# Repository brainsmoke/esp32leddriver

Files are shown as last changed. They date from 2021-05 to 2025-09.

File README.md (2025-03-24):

# LED Driver for 3D sculptures based on an ESP32 with PSRAM + an STM32F0XX

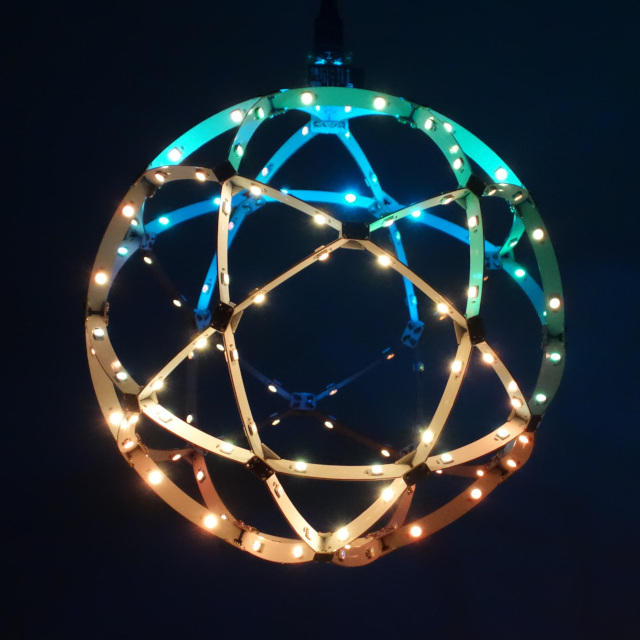
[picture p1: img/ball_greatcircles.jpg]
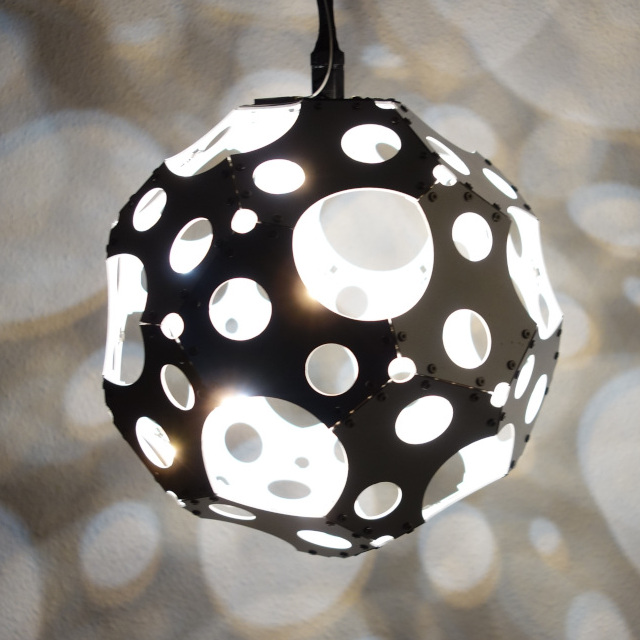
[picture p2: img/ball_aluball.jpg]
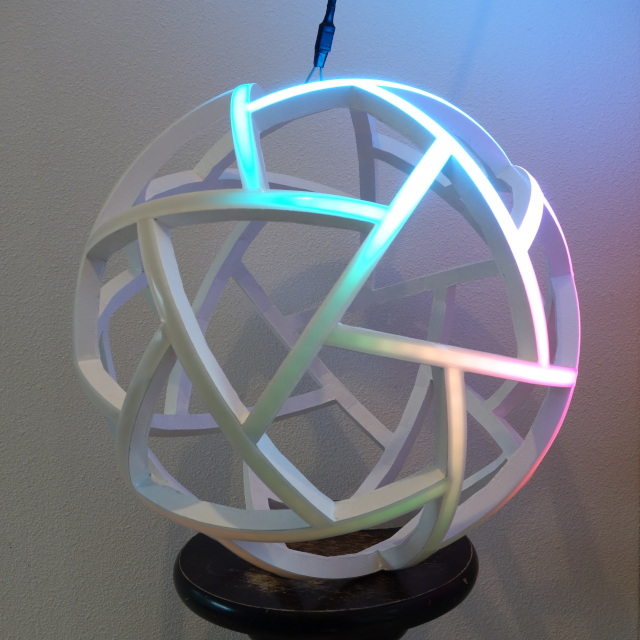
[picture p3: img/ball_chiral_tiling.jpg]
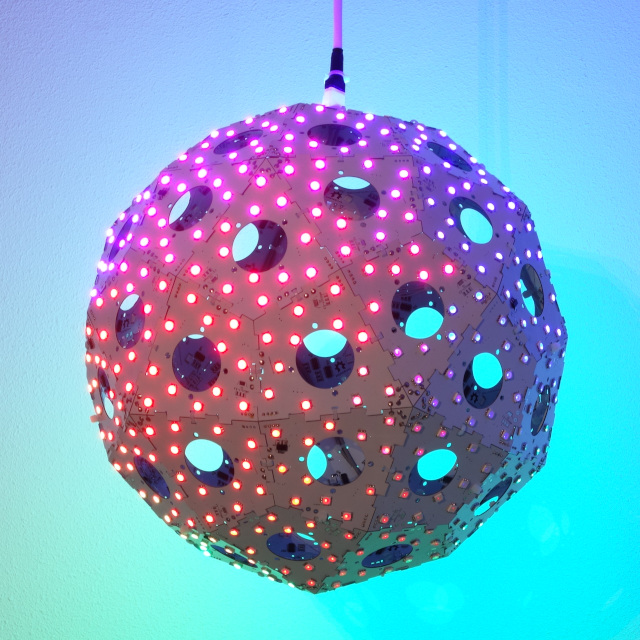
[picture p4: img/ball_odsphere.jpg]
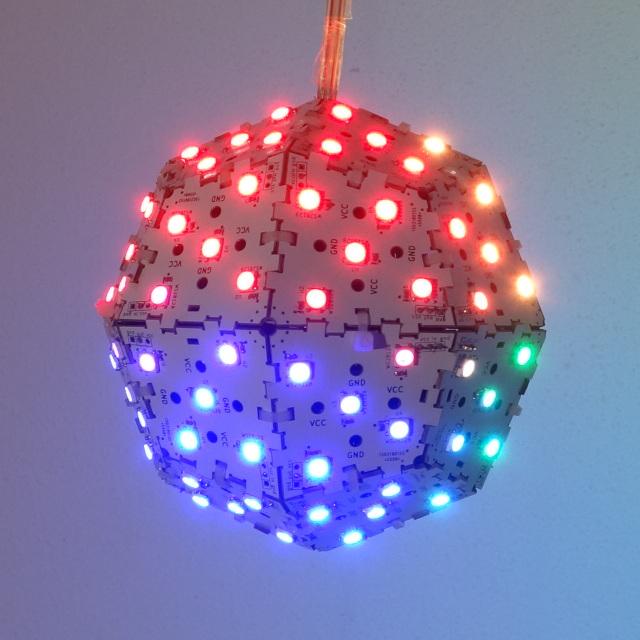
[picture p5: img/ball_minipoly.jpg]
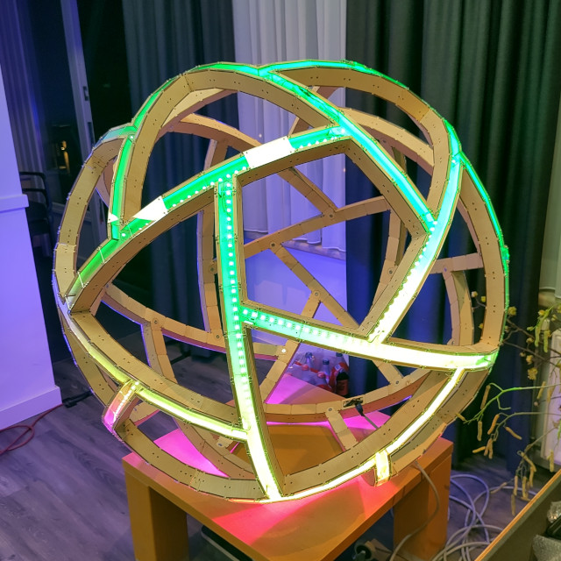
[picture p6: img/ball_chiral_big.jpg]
     

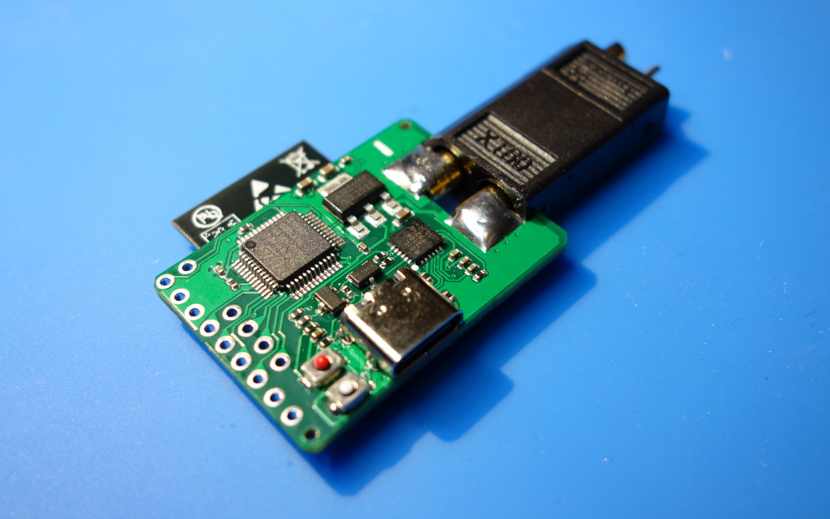
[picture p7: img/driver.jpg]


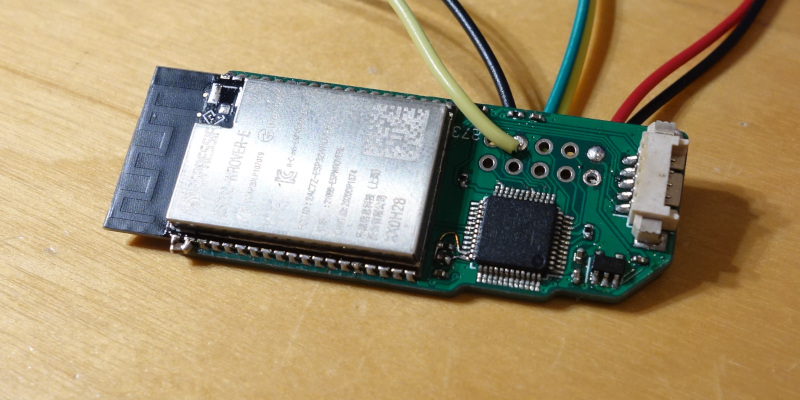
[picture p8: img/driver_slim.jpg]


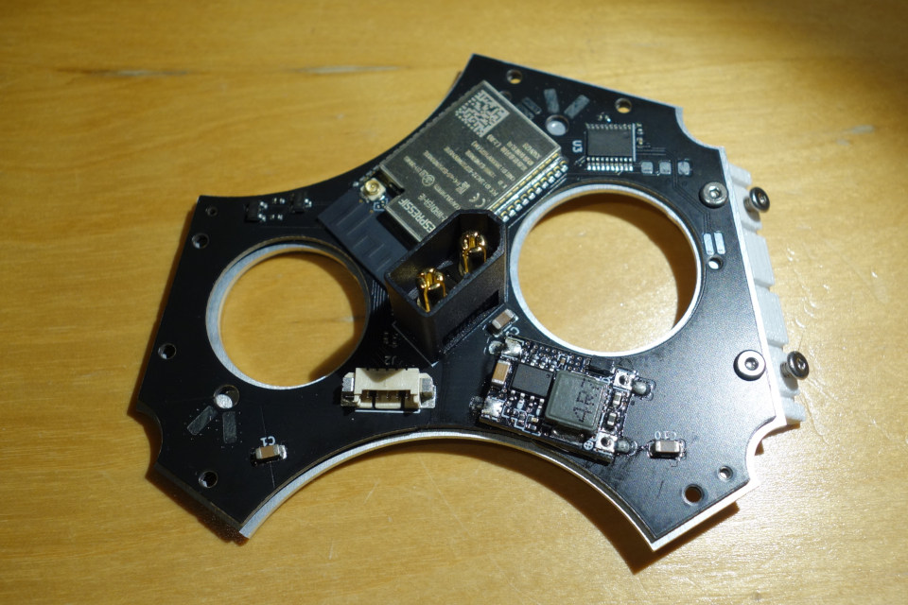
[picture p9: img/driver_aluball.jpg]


# Design:

```
   programming &
  micropython REPL
         ||
     .--------.
     |  usb   |
     |   to   |
     | serial | 
     '--------'
         ||
   .--------------.                               _____________.--
   |  ESP32-D0WD  |          (UART)              |             |-- multiple LED strands
   |   8M PSRAM   |-- 16bit/color LED frames --> |  STM32F0XX  |-- (temporal dithered)
   |  16M FLASH   |                              |_____________|--
   '--------------'                                            '--

```

# ESP Code `firmware/esp32/`

- Running micropython

- 60 FPS 16bit/color (48bit) animation with some routines written in C for speed.

- Animations use 3D-coordinates of the LEDs, as well as the direction they're pointing at

- Gamma correction & support for multiple LED orderings.

- Cached animation frames to prevent garbage collection hiccups

- Web interface (HTTPS capable, but no automatic cert. updates)

# STM32 Code `firmware/stm32/`

## Protocol

Sending a frame: `( [16 bit brightness]* [ FF FF FF F0 ] )*`

Brightness must be little endian integers in the (inclusive) range `[0 .. 0xFF00]`

`[ FF FF FF F0 ]` is an end of frame marker and allows the protocol to synchronize
in the event of an uneven number of bytes being written to the serial port

The firmware is completely agnostic about the color ordering.

Some of the following firmwares allow for tuning of the pulse interval:

`( [16 bit number]* [ FF FF FF F3 ] )*`

The given number is the number of cycles outputting a byte should take.
(Useful for increasing the FPS and thus improving temporal dithering.

## `dither16.bin`

Read in 16bit/color data in, drive 8 ws2812 LED strips in parallel

## `strip4.bin`

Read in 16bit/color data in, drive 4 ws2812 LED strips in parallel

## `strip5.bin`

Read in 16bit/color data in, drive 5 ws2812 LED strips in parallel,
Supports tuning the pulse interval.

## `relayball.bin`

Read in 16bit/color data in, drive 4 circuit-routed ws2812 LED meshes.
Small LED strands are connected through PADAUK based relay-chips
(`firmware/pdk/relay/`) that use in-band messages to build up routing
circuits.

## `uartball16.bin`

Drives up-to 8 busses with PADAUK based LED drivers which read 38400 baud
uart. `firmware/pdk/softpwm/`

##  `dither8.bin`

Older code using a different input protocol, reads 8bit/color data & transforms this to 16 bit colors
after gamma correction

# STM32 Tester code

## `jitter_timer.bin`

Tester for PADAUK ws2812 relay chips. `firmware/pdk/relay/`

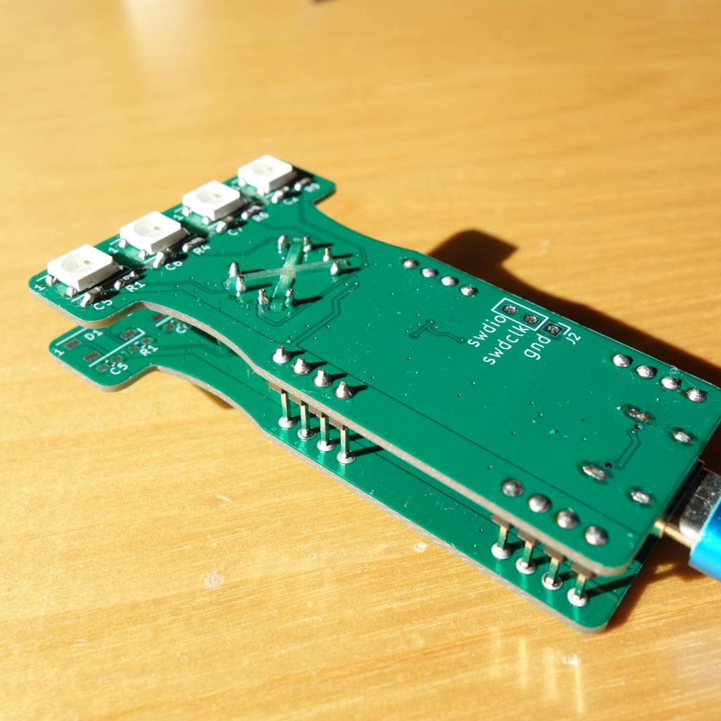
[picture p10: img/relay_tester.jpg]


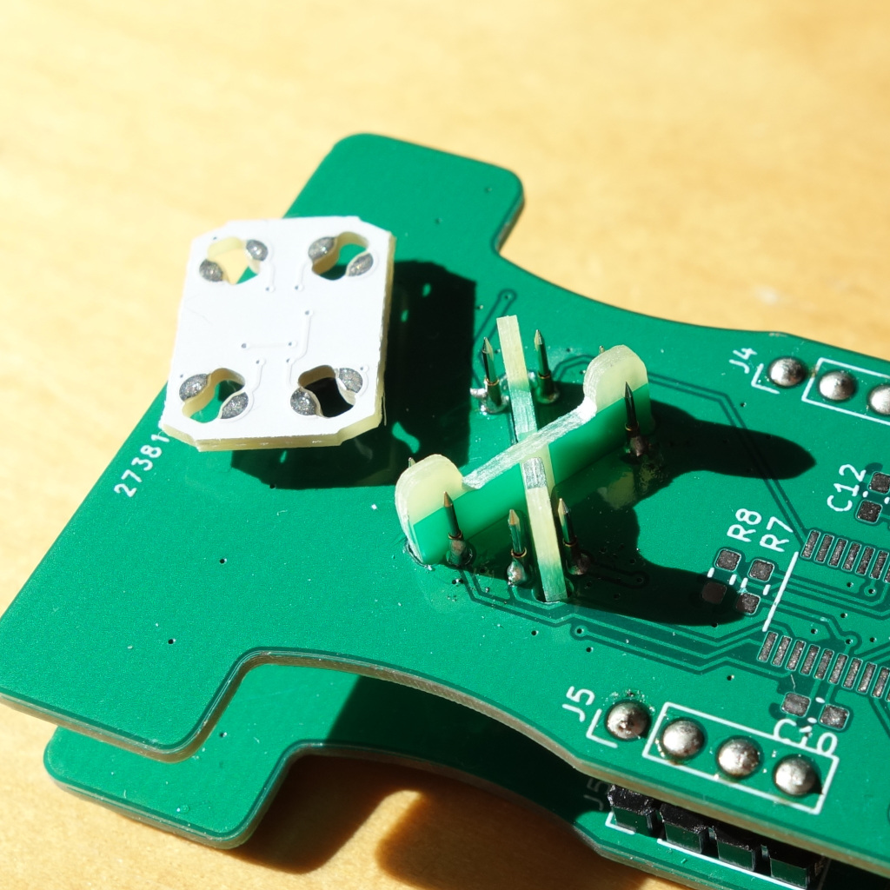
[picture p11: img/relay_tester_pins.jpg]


Tests for functionality and measures the clock speed deviation (for binning).

## `timing_experiment.bin`

Dynamically adjust the `T1H` and `T1L` intervals from the ws2812 protocol to
test its limits.

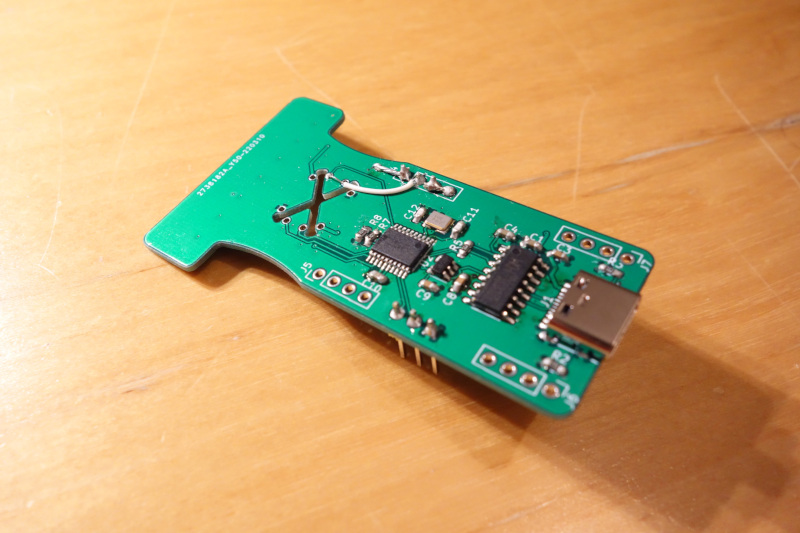
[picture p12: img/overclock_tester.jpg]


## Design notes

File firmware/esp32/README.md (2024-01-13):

# ESP32 firmware upload / build

## Upload pre-built firmware

```bash
# make sure you are a member of the dailout group (so you can talk to the serial device)
sudo usermod -a -G dialout "$USER"
# you might need to log in again for it to take effect or you could do:
# (but newgrp only works for the current shell)
newgrp -

# install pip (using whatever package manager you have)
sudo apt install python3-pip

sudo pip3 install esptool
sudo pip3 install adafruit-ampy

# replace "/dev/ttyUSB0" with the correct device name
export ESPTTY="/dev/ttyUSB0"
tools/flash.sh
tools/micropython_screen.sh
ctrl-c
>>>setup()
(enter wifi creds, will be stored in flash)
>>>failsafe()
(enter failsafe wifi access point creds, will be stored in flash)
ctrl-d

```

For spheres other than the default 'greatcircles', replace `tools/flash.sh` with 
`tools/flash.sh <configuration>` (see: [[conf]](conf/)).

## Build firmware

```bash

# should be correct, but not tested from a clean VM

git clone https://github.com/brainsmoke/esp32leddriver

# ESP-IDF
git clone -b v4.4.3 --recursive https://github.com/espressif/esp-idf.git
(cd esp-idf; ./install.sh)

# clone of micropython using esp32 native vfs, also has settings for http[s] server /mbedtls
git clone https://github.com/brainsmoke/micropython -b leddriver-post-1.19
(cd micropython/ports/esp32 ; make submodules)

# Edit setenv.sh to set the correct build directories:
cd esp32leddriver/firmware/esp32
"$EDITOR" ./tools/setenv.sh

./tools/domake.sh
# firmware should be in micropython/ports/esp32/build-LEDBALL/firmware.bin

./tools/doflash.sh

```

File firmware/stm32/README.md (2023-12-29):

# m02812: WS2812 bitbang routine for a 48MHz cortex m0

```
make
gdb-multiarch dither16.elf
set mem inaccessible-by-default off
target extended-remote /dev/ttyACM0
monitor swdp_scan
attach 1
load
run
```

# Template code

Based on the template code at:
https://github.com/asquared/stm32f0-barebones-template

which is a stripped-down version of:
https://github.com/szczys/stm32f0-discovery-basic-template

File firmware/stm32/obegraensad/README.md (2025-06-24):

# IKEA OBEGRÄNSAD driver code

* Desolder the MCU (U1) on the bottom panel (looking at the silkscreen text, the panels are mounted upside down).
  It's the only chip that's only present on one of the boards.
* (Only) desolder the data-out to data-in wires connecting the panels (the potting compound can be easily removed with some isopropanol)
* All signals to the panel need to be boosted to 5V (for example using a 74HCT245)
* Leave the VCC/GND/CLK/Latch/Not-output-enable wires intact
* Connect the data-in pins to the esp32leddriver board (or another board with an stm32f0xx running this firmware)
* Add ground wires next to the data wires for signal integrity
* The attached USB cable is power-only, but can be replaced
* The side-button is accessible via a pad on R5 on the bottom panel, it is pulled to ground when pressed.
* There is an alternative firmware for the STM32F042 which reads frames from USB-serial, see: [usb_proto/firmware/obegraensad](https://github.com/brainsmoke/usb_proto/tree/main/firmware/obegraensad)

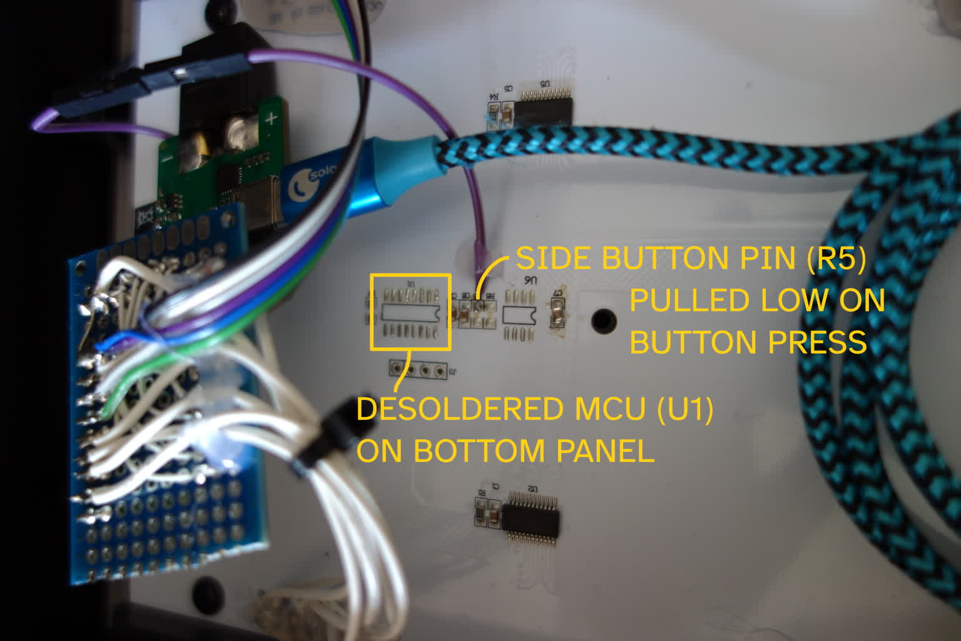
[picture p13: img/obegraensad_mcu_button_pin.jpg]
close-up of the removed MCU footprint & pad to connect to the button


## Pinout (panel, data-in side):

Left-to-right, silkscreen orientation:

* VCC
* Latch
* Clock
* Data in
* Not Output Enable
* Ground

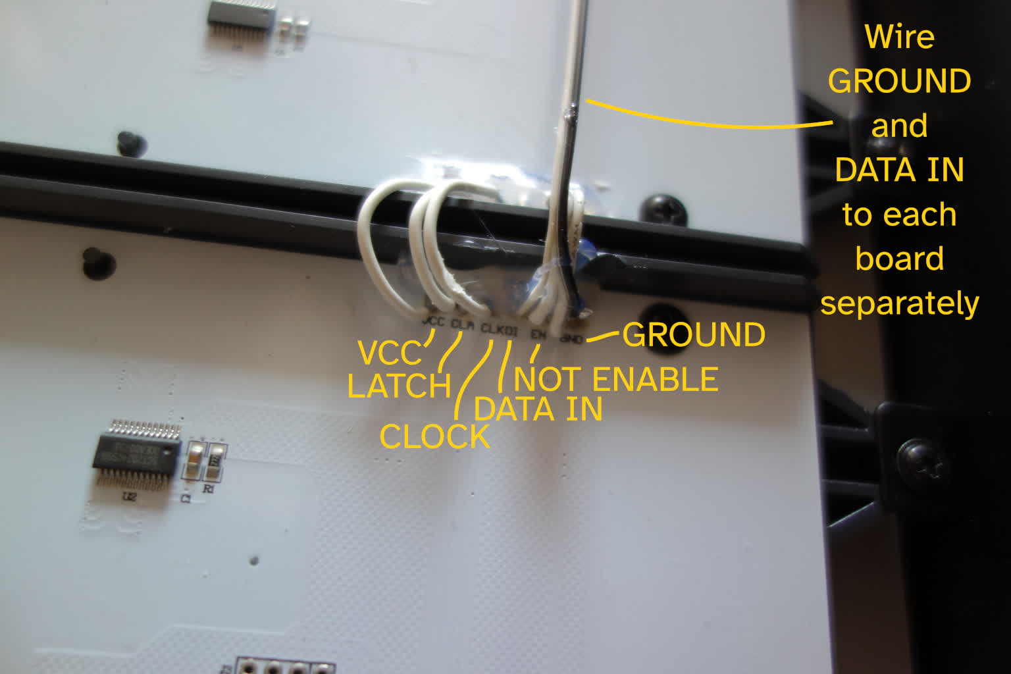
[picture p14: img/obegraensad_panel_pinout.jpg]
photo of pinout on the panels


## Pinout (driver board):

Output, boosted to 5V signalling:

* PA0: Data in, top panel
* PA1: Data in, 2nd panel
* PA2: Data in, 3rd panel
* PA3: Data in, bottom panel
* PA4: Clock (wired to bottom panel)
* PA5: Latch (wired to bottom panel)
* PA6: Not Output Enable (wired to bottom panel)

Input:

* PA10: UART RX, 1MBaud (In my case, written to by one the esp32's UARTs)

The pinout on the esp32leddriver board (v4.0, with integrated level shifters):

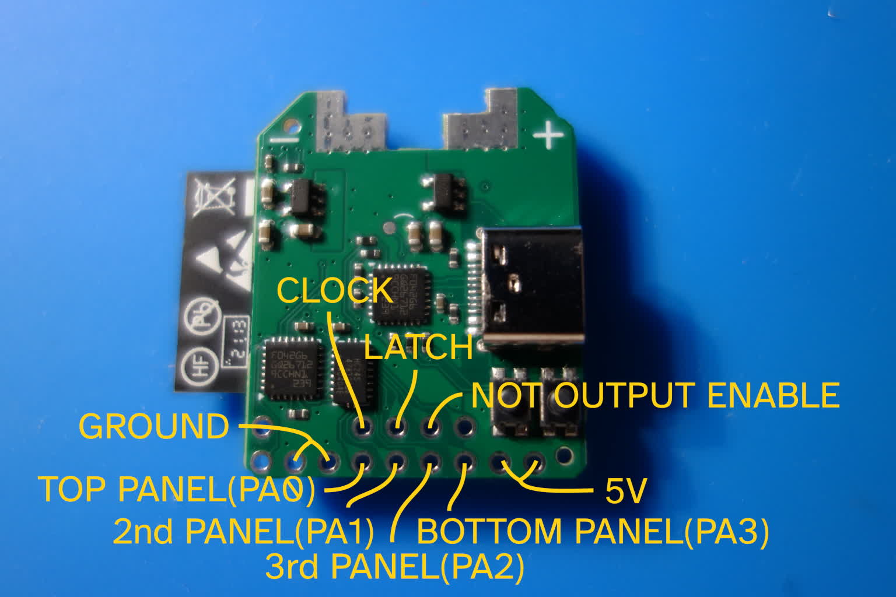
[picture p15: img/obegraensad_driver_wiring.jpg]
photo of pinout on the esp32leddriver board (v4.0)


## Protocol to the STM32 driver:

Signal: UART at 1MBaud

Sending a frame: `( [16 bit brightness]*256 [ FF FF FF F0 ] )*`

Brightness must be little endian integers in the (inclusive) range `[0 .. 0xFF00]`

One brightness value per pixel. Pixels are addressed left to right, top to bottom.

`[ FF FF FF F0 ]` is an end of frame marker and allows the protocol to synchronize
in the event of an uneven number of bytes being written to the serial port

## Picture of wiring setup

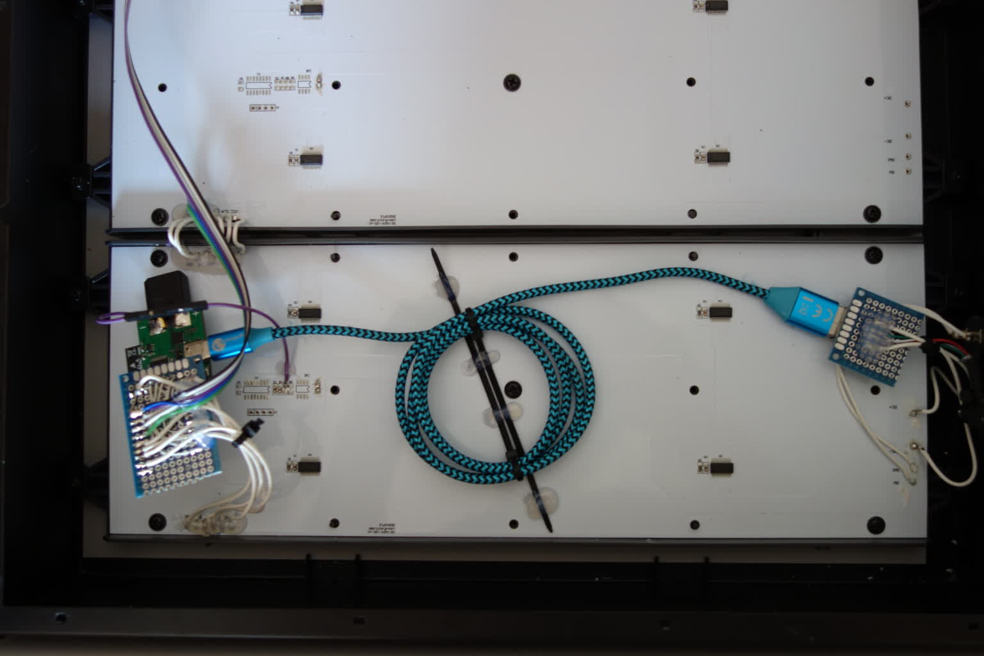
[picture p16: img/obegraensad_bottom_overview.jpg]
photo giving an overview of the wiring situation


## Animations software on the ESP32

My driver board contains an ESP32 which serves animations over a UART.
GPIO13 (uart-tx) of the ESP32 is connected to PA10 on the STM32 (uart-rx)

The ESP32 runs the animation software from [this repo](../../esp32).
instead of `tools/flash.sh`, run `tools/flash.sh obegraensad` to program the right configuration for this
project.

## Button

The button on the side connects to ground when pressed, and is accessable via a pad on the bottom panel.
I've connected it to GPIO2 of the ESP32 on my driver board.

## Other IKEA OBEGRÄNSAD hacks

[ph1h/ikea-led-obegraensad](https://github.com/ph1p/ikea-led-obegraensad)

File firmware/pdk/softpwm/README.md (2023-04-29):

# 3-channel 16 bit software PWM LED driver

* 1800Hz, 16-bit PWM (12-bit + 4 bits dithering)
* 3-channels, almost evenly spaced phase offsets
* inverse polarity compared to WS2811 (pin high = LED on)
* UART based signalling, 38400 baud, 16 bit values, (2x 8bit uart frame/channel, little endian)
* end-of-frame is determined using a reset delay (between 1-2msec)
* no output line, led index is hard-coded in the firmware
* tested on PFS154 & PMS150C

https://github.com/brainsmoke/softpwmpdk

## Write firmware:

```
$ ./write.sh 0 # use the first 6 bytes as pixel data

$ ./write.sh 1 # use bytes 6..11 as pixel data
```

## Read address:

```
$ ./read_address.sh
Address: 0
```

## Change address:

Even on one-time programmable chips, a limited number of address changes
if possible:

```
$ ./change_address.sh 4   # this is the fourth chip in the LED strip
```

OTP parts like PMS150C start out with a ROM with all ones, bits can only
be flipped once, from 1 to 0.

The following scheme makes it possible to update the chip's address many times:

The code reads (13 or 14 bit) opcodes at the end of the code section.
opcodes where the high bits are set to 0 are skipped. The
first opcode with non-zero high bits contains the address in its low byte.

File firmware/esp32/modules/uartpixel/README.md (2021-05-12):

UART / Timer based framebuffer queue
=================================================

Hide garbage-collection jitter by queueing enough frames to clock out
at regular intervals.

For the python half of the implementation, see: [uartpixel.py](../../fs/uartpixel.py)

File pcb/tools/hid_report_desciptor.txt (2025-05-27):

Usage Page (Generic Desktop)
Usage (Keypad)
Collection (Application)
Usage Page (Keyboard)

Usage (Generic Desktop, System Sleep)
Usage (Generic Desktop, System Wake Up)
Usage (Generic Desktop, System Power Down)
Usage (Generic Desktop, System Warm Restart)

Usage (Consumer, Play)
Usage (Consumer, Pause)
Usage (Consumer, Stop)
Usage (Consumer, Record)

Usage (Consumer, Rewind)
Usage (Consumer, Fast Forward)
Usage (Consumer, Scan Previous Track)
Usage (Consumer, Scan Next Track)

Usage (Keyboard, Volume Down)
Usage (Keyboard, Volume Up)
Usage (Consumer, AL Calculator)
Usage (Keyboard, 0x04)

Report Size (1)
Report Count (16)
Input (Data, Variable, Absolute)

Report Size (8)
Report Count (1)
Input (Constant)

End Collection

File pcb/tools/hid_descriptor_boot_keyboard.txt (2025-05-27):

Usage Page (Generic Desktop)
Usage (Keyboard)
Collection (Application)
Report Size (1)
Report Count (8)
Usage Page (Keyboard)
Usage Minimum (224)
Usage Maximum (231)
Logical Minimum (0)
Logical Maximum (1)
Input (Data, Variable, Absolute)
Report Count (1)
Report Size (8)
Input (Constant)
Report Count (5)
Report Size (1)
Usage Page (LED)
Usage Minimum (1)
Usage Maximum (5)
Output (Data, Variable, Absolute)
Report Count (1)
Report Size (3)
Output (Constant)
Report Count (6)
Report Size (8)
Logical Minimum (0)
Logical Maximum(255)
Usage Page (Keyboard)
Usage Minimum (0)
Usage Maximum (255)
Input (Data, Array)
End Collection

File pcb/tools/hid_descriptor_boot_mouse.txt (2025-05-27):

Usage Page (Generic Desktop)
Usage (Mouse)
Collection (Application)
Usage (Pointer)
Collection (Physical)
Report Count (3)
Report Size (1)
Usage Page (Button)
Usage Minimum (1)
Usage Maximum (3)
Logical Minimum (0)
Logical Maximum (1)
Input (Data, Variable, Absolute)
Report Count (1)
Report Size (5)
Input (Constant)
Report Size (8)
Report Count (2)
Usage Page (Generic Desktop)
Usage (X)
Usage (Y)
Logical Minimum (-127)
Logical Maximum (127)
Input (Data, Variable, Relative)
End Collection
End Collection

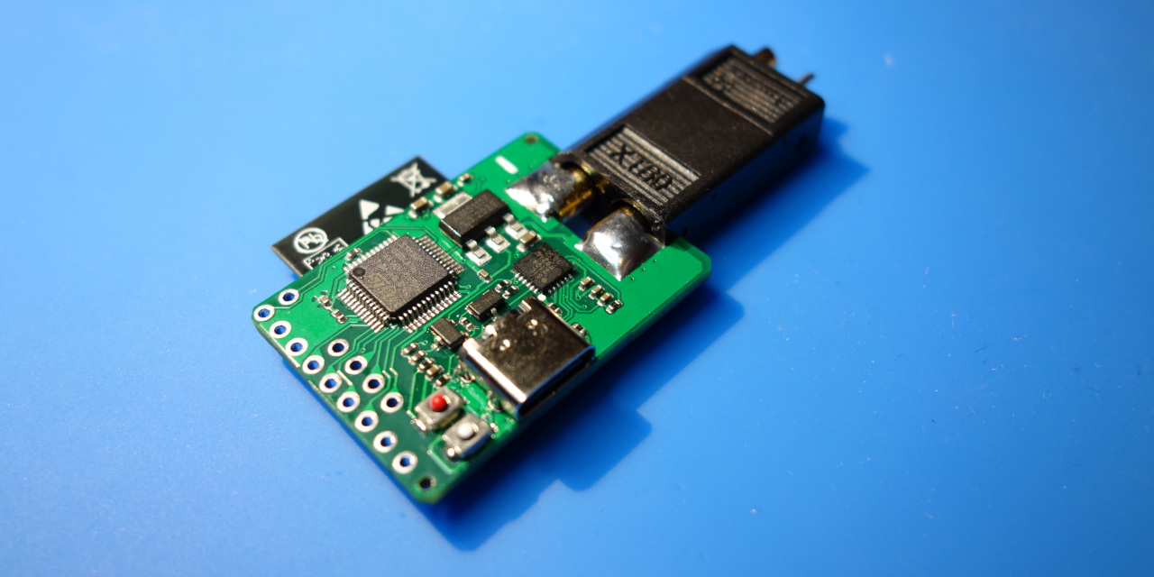
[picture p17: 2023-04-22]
img/header.jpg

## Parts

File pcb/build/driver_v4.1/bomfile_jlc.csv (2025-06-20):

Comment | Designator | Footprint | JLCPCB Part #
1uF | C1,C5,C6,C7,C8 | Capacitor_SMD:C_0402_1005Metric | C52923
10uF | C2,C4,C9 | esp32-wrover:C_0603_1608Metric | C19702
USB_C_Receptacle_USB2.0 | J2 | footprints:USB_C_Receptacle_HRO_TYPE-C-31-M-12 | C165948
470 Ohm | R10,R12 | Resistor_SMD:R_0402_1005Metric | C25117
10k | R5,R6,R11,R13,R14 | Resistor_SMD:R_0402_1005Metric | C25744
5.1k | R8,R9 | Resistor_SMD:R_0402_1005Metric | C25905
SW_SPST | SW1,SW2 | Button_Switch_SMD:SW_Push_1P1T_NO_CK_KMR2 | C318893
ME6211C33M5G-N | U3 | footprints:SOT-23-5 | C82942
74HCT245 | U6 | Package_DFN_QFN:DHVQFN-20-1EP_2.5x4.5mm_P0.5mm_EP1x3mm | C547496
STM32F042G6Ux | U2,U4 | Package_DFN_QFN:QFN-28_4x4mm_P0.5mm | C2971720

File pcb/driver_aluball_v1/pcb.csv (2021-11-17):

Comment | Designator | Footprint | LCSC part number
1uF | C7 | Capacitor_SMD:C_0402_1005Metric | C52923
100nF | C8,C5 | Capacitor_SMD:C_0402_1005Metric | C1525
10uF | C9,C10,C1 | Capacitor_SMD:C_1206_3216Metric | C13585
Conn_01x05_Male | J2 | Connector_Molex:Molex_PicoBlade_53261-0571_1x05-1MP_P1.25mm_Horizontal | C225114
AO3400 | Q1,Q2 | Package_TO_SOT_SMD:SOT-23 | C20917
10k | R6,R7,R3,R4,R5,R11 | Resistor_SMD:R_0402_1005Metric | C25744
ESP32-WROVER-IE(16MB) | U1 | QFN-38_EP_18.0x31.4x1.27P-1 | C701352
STM32F030F4Px | U3 | Package_SO:TSSOP-20_4.4x6.5mm_P0.65mm | C89040

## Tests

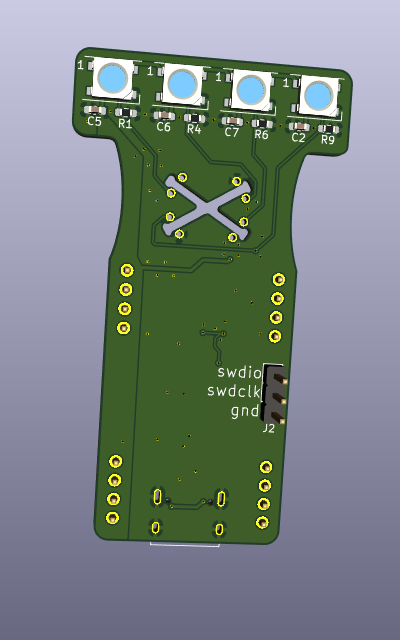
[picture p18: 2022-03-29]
pcb/relay_tester/top.png

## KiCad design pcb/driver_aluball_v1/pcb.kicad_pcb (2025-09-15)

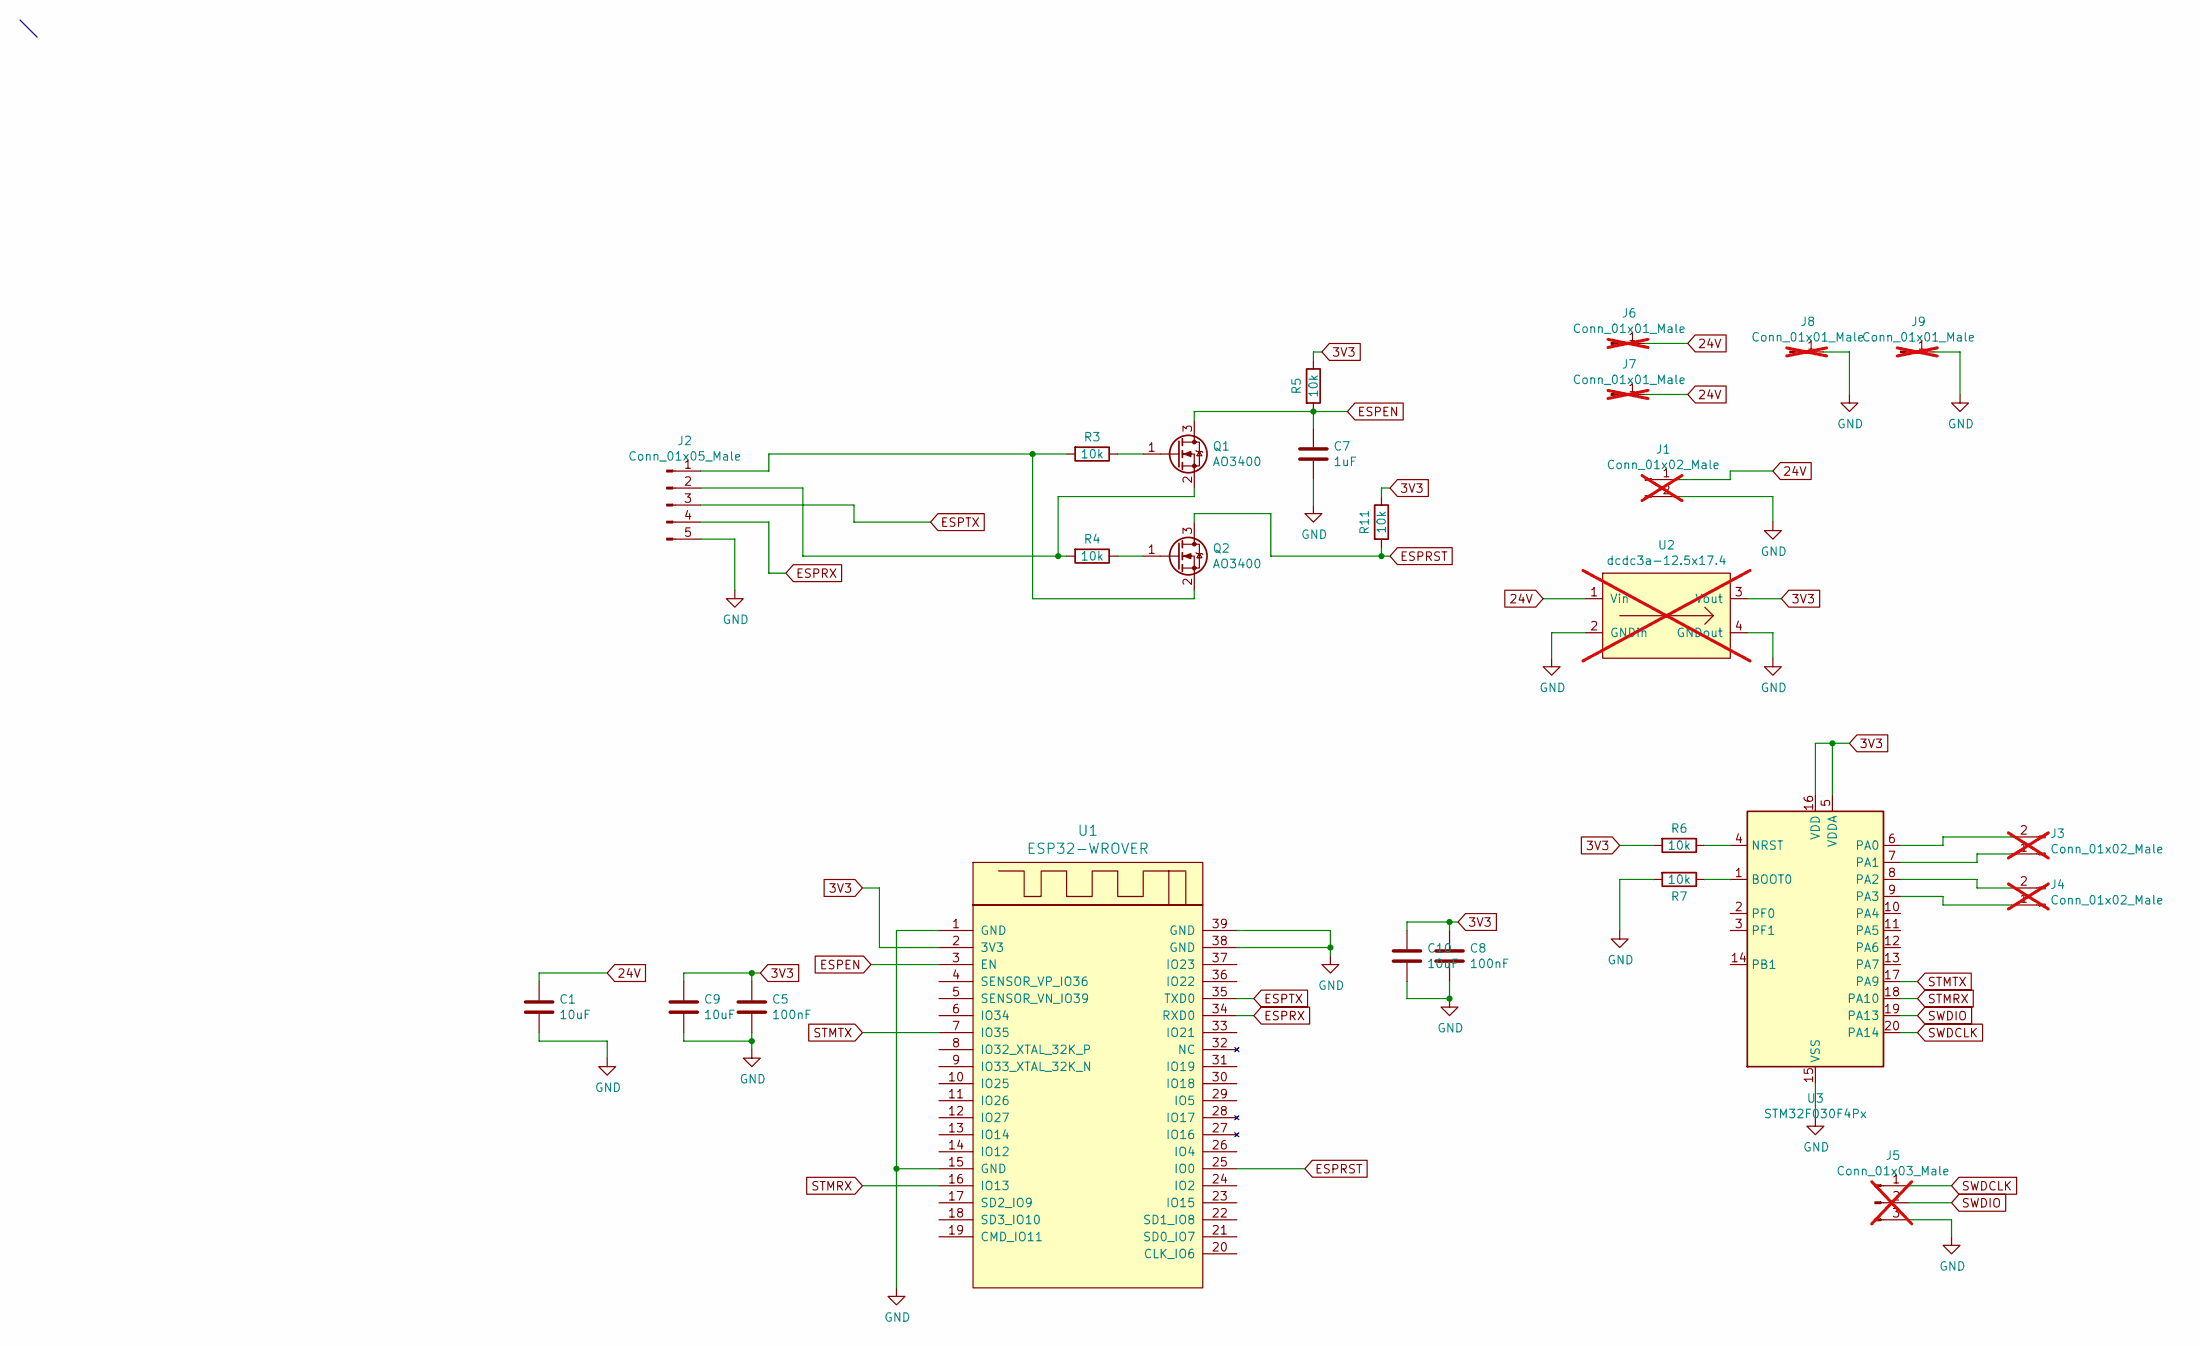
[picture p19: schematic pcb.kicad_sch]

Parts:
C1, C9, C10: 10uF; C_1206_3216Metric; LCSC C13585
C5, C8: 100nF; C_0402_1005Metric; LCSC C1525
C7: 1uF; C_0402_1005Metric; LCSC C52923
J1: Conn_01x02_Male; xt60-pcb; not fitted
J2: Conn_01x05_Male; Molex_PicoBlade_53261-0571_1x05-1MP_P1.25mm_Horizontal; LCSC C225114
J3, J4: Conn_01x02_Male; PinHeader_1x02_P2.54mm_Vertical; not fitted
J5: Conn_01x03_Male; PinHeader_1x03_P2.54mm_Vertical; not fitted
J6, J7, J8, J9: Conn_01x01_Male; solderpad1; not fitted
Q1, Q2: AO3400; SOT-23; LCSC C20917
R3, R4, R5, R6, R7, R11: 10k; R_0402_1005Metric; LCSC C25744
U1: ESP32-WROVER; XCVR_ESP32-WROVER; LCSC C701352
U2: dcdc3a-12.5x17.4; not fitted
U3: STM32F030F4Px; TSSOP-20_4.4x6.5mm_P0.65mm; LCSC C89040

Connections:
3V3: C5.1, C8.1, C9.1, C10.1, R5.1, R6.2, R11.1, U1.2 (3V3), U2.3 (Vout), U3.5 (VDDA), U3.16 (VDD)
24V: C1.1, J1.1, J6.1, J7.1, U2.1 (Vin)
ESPEN: C7.1, Q1.3 (D), R5.2, U1.3 (EN)
ESPRST: Q2.3 (D), R11.2, U1.25 (IO0)
ESPRX: J2.4, U1.34 (RXD0)
ESPTX: J2.3, U1.35 (TXD0)
GND: C1.2, C5.2, C7.2, C8.2, C9.2, C10.2, J1.2, J2.5, J5.3, J8.1, J9.1, R7.2, U1.1 (GND), U1.15 (GND), U1.38 (GND), U1.39 (GND), U2.2 (GNDin), U2.4 (GNDout), U3.15 (VSS)
unnamed: J2.1, Q2.2 (S), R3.2
unnamed: J2.2, Q1.2 (S), R4.2
unnamed: J3.1, U3.7 (PA1)
unnamed: J3.2, U3.6 (PA0)
unnamed: J4.1, U3.9 (PA3)
unnamed: J4.2, U3.8 (PA2)
unnamed: Q1.1 (G), R3.1
unnamed: Q2.1 (G), R4.1
unnamed: R7.1, U3.1 (BOOT0)
unnamed: R6.1, U3.4 (NRST)
STMRX: U1.16 (IO13), U3.18 (PA10)
STMTX: U1.7 (IO35), U3.17 (PA9)
SWDCLK: J5.1, U3.20 (PA14)
SWDIO: J5.2, U3.19 (PA13)

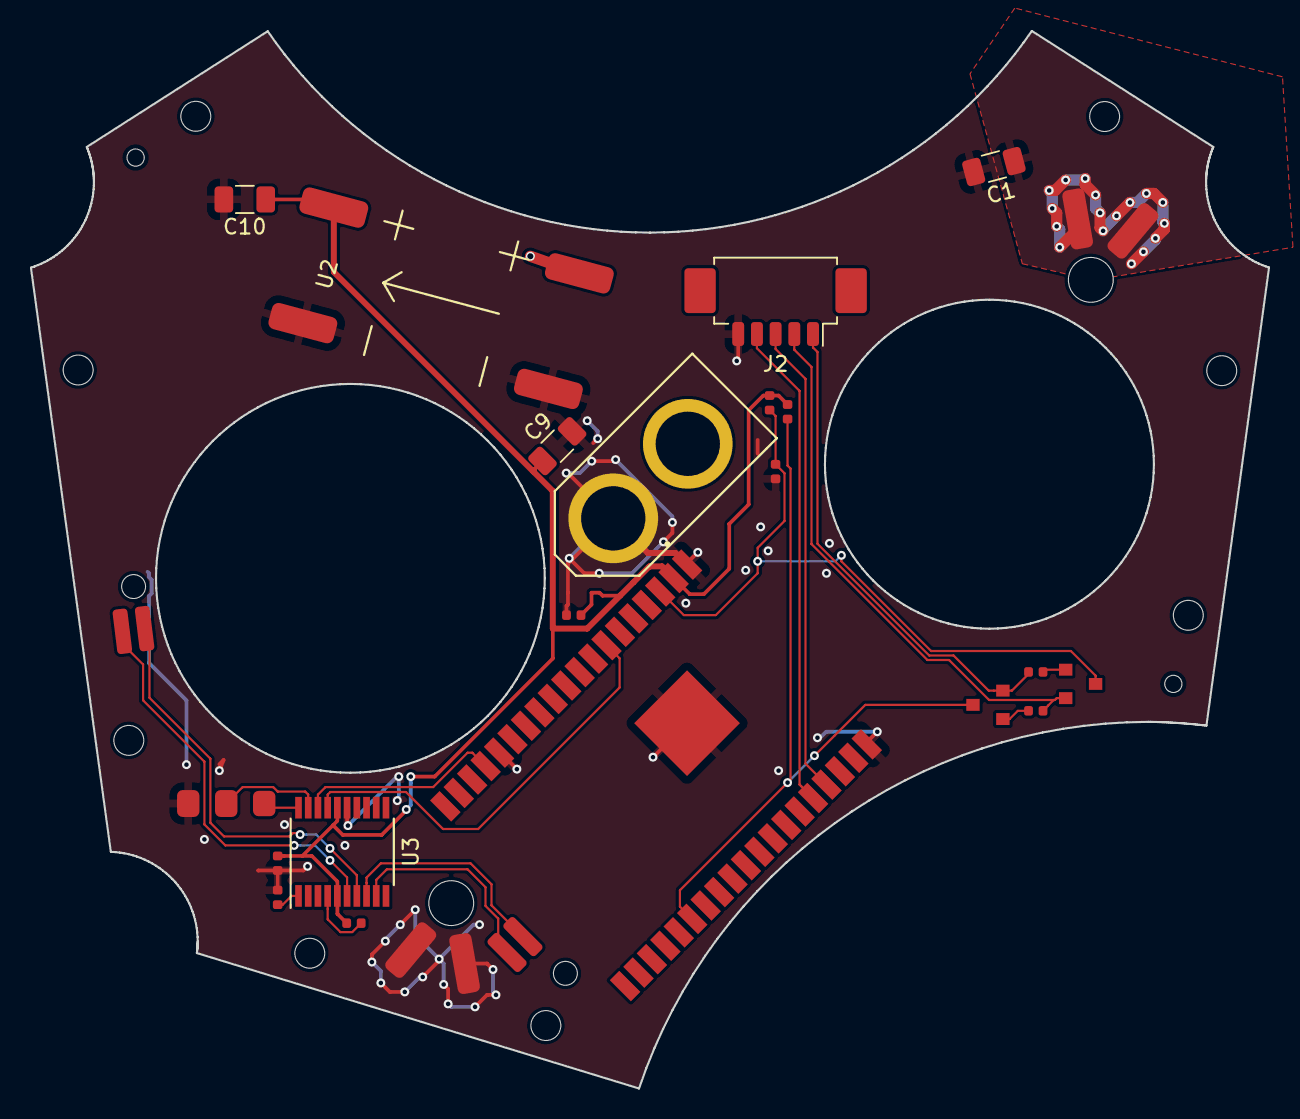
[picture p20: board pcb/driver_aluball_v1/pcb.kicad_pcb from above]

Board: 2 copper layers, 82.8 x 70.7 mm, 26 parts (0 on the bottom side), 21 nets.

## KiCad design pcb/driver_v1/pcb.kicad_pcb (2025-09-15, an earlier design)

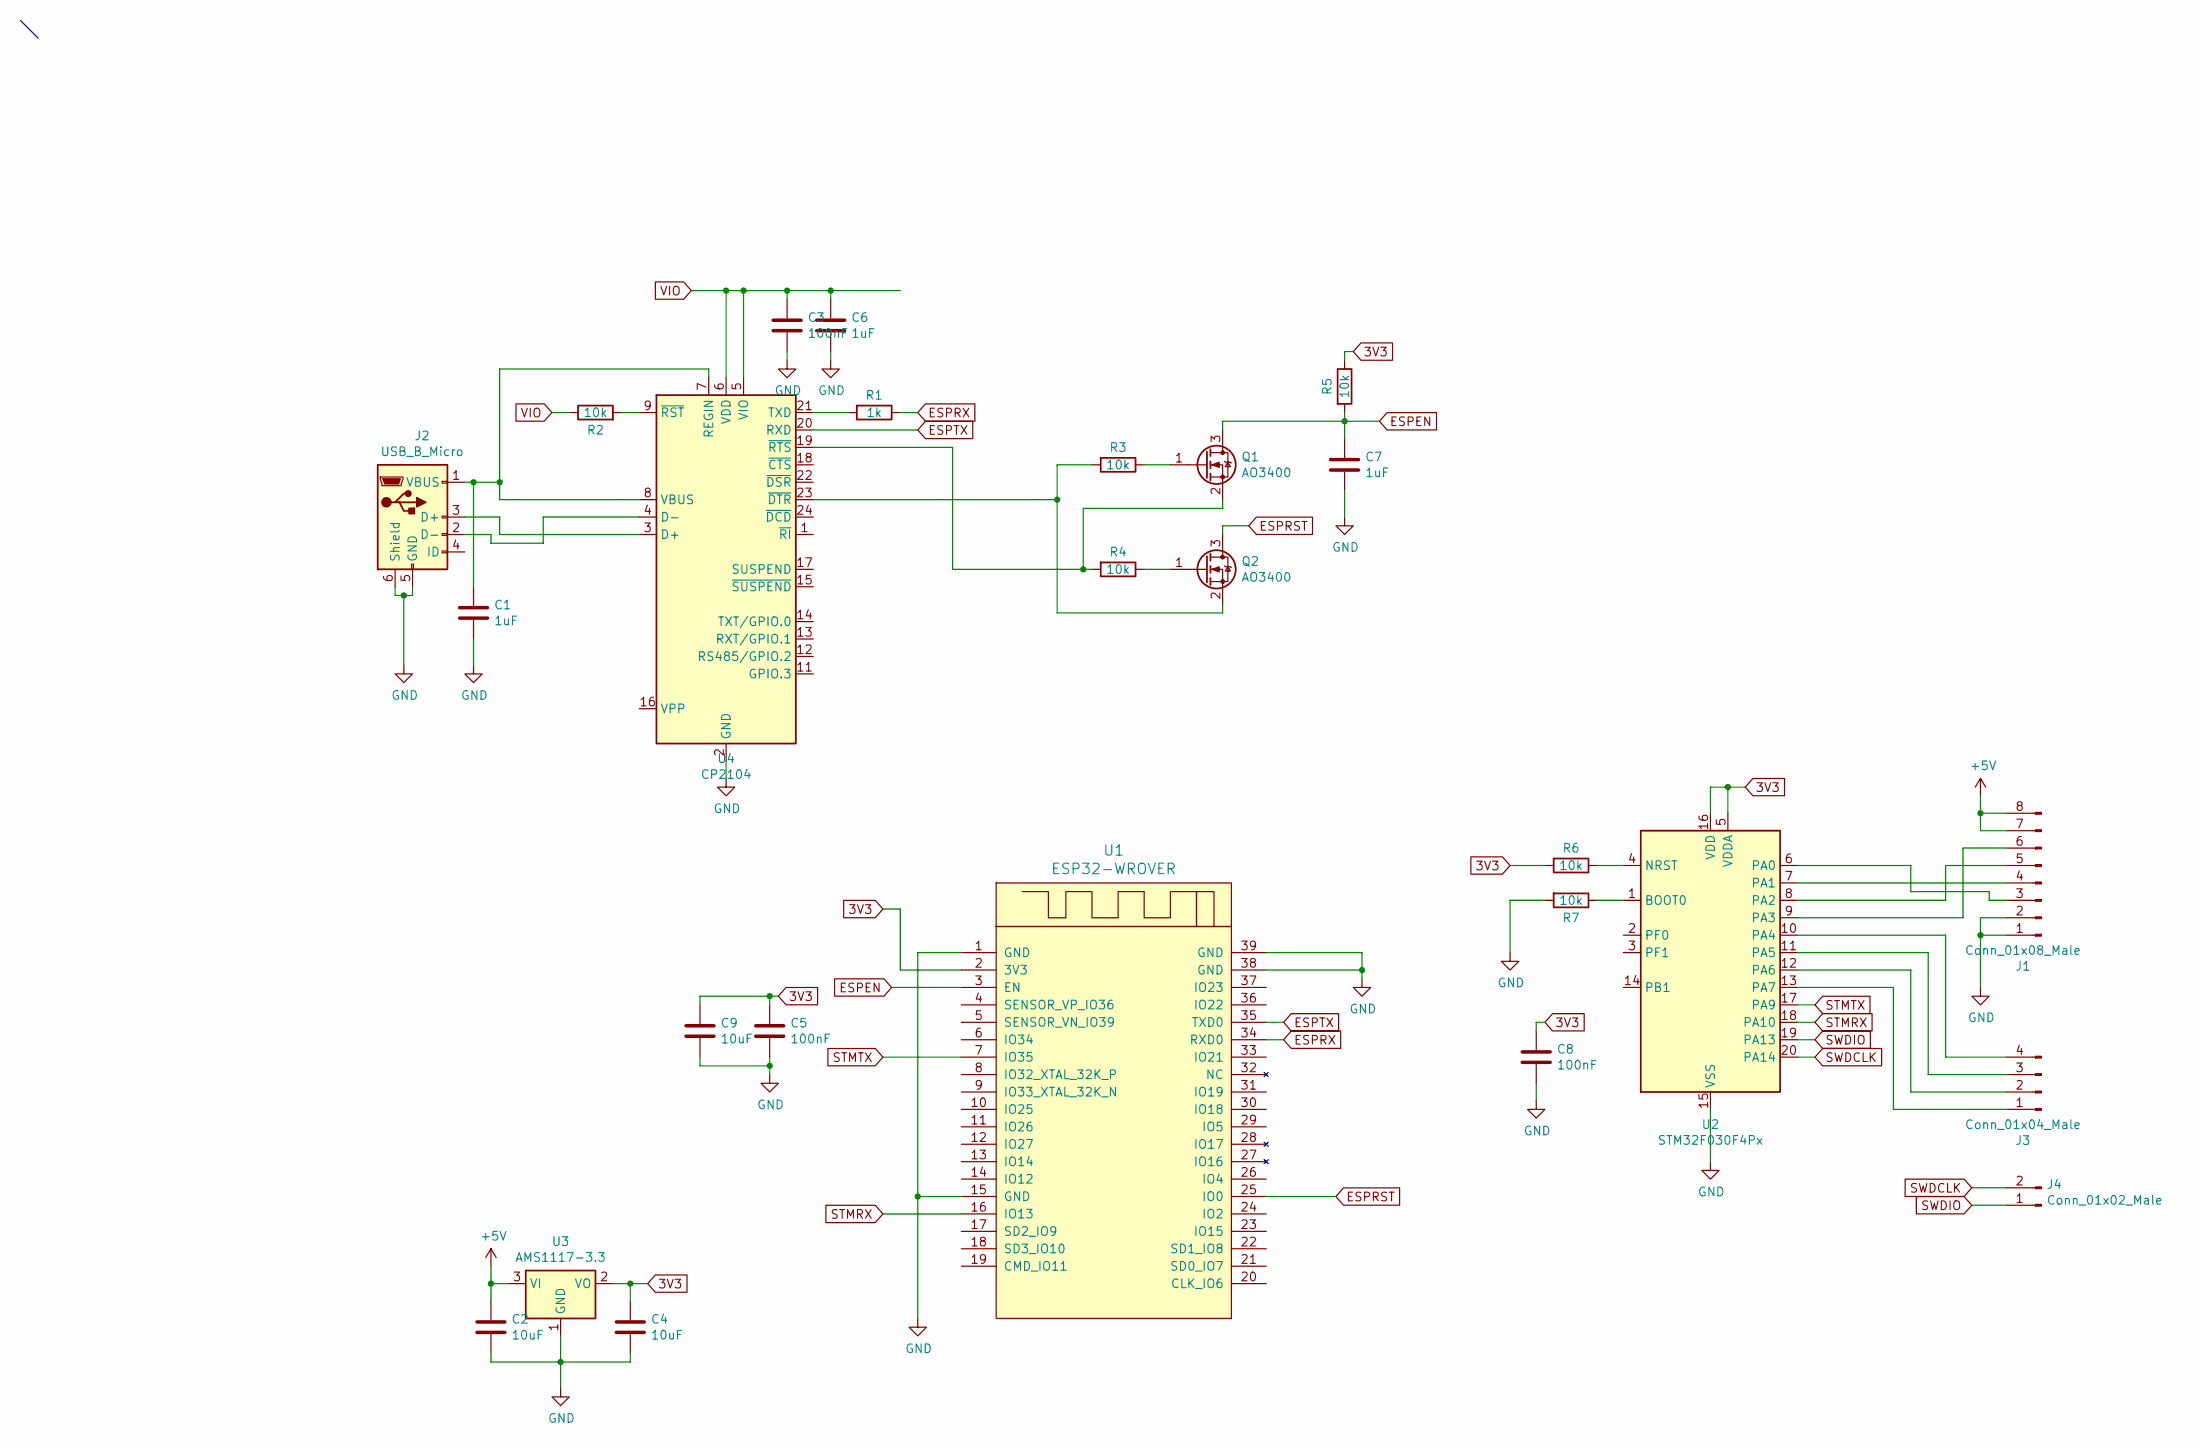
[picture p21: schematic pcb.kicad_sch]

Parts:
C1, C6, C7: 1uF; C_0603_1608Metric; LCSC C15849
C2, C4, C9: 10uF; C_0603_1608Metric; LCSC C15850
C3, C5, C8: 100nF; C_0603_1608Metric; LCSC C14663
J1: Conn_01x08_Male; PinHeader_1x08_P2.54mm_Vertical
J2: USB_B_Micro; USB_Micro-B_Molex_47346-0001
J3: Conn_01x04_Male; PinHeader_1x04_P2.54mm_Vertical
J4: Conn_01x02_Male; PinHeader_1x02_P2.54mm_Vertical
Q1, Q2: AO3400; SOT-23; LCSC C20917
R1: 1k; R_0603_1608Metric_nolabel; LCSC C21190
R2, R3, R4, R5, R6, R7: 10k; R_0603_1608Metric_nolabel; LCSC C25804
U1: ESP32-WROVER; XCVR_ESP32-WROVER
U2: STM32F030F4Px; TSSOP-20_4.4x6.5mm_P0.65mm; LCSC C89040
U3: AMS1117-3.3; SOT-223-3_TabPin2; LCSC C6186
U4: CP2104; QFN-24-1EP_4x4mm_P0.5mm_EP2.6x2.6mm; LCSC C47742

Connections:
3V3: C4.1, C5.1, C8.1, C9.1, R5.1, R6.2, U1.2 (3V3), U2.5 (VDDA), U2.16 (VDD), U3.2 (VO)
+5V: C2.1, J1.7, J1.8, U3.3 (VI)
ESPEN: C7.1, Q1.3 (D), R5.2, U1.3 (EN)
ESPRST: Q2.3 (D), U1.25 (IO0)
ESPRX: R1.1, U1.34 (RXD0)
ESPTX: U1.35 (TXD0), U4.20 (RXD)
GND: C1.2, C2.2, C3.2, C4.2, C5.2, C6.2, C7.2, C8.2, C9.2, J1.1, J1.2, J2.5 (GND), J2.6 (Shield), R7.2, U1.1 (GND), U1.15 (GND), U1.38 (GND), U1.39 (GND), U2.15 (VSS), U3.1 (GND), U4.2 (GND), U4.25 (GND)
unnamed: J1.3, U2.6 (PA0)
unnamed: J1.4, U2.7 (PA1)
unnamed: J1.5, U2.8 (PA2)
unnamed: J1.6, U2.9 (PA3)
unnamed: J2.3 (D+), U4.3 (D+)
unnamed: J2.2 (D-), U4.4 (D-)
unnamed: C1.1, J2.1 (VBUS), U4.7 (REGIN), U4.8 (VBUS)
unnamed: J3.1, U2.13 (PA7)
unnamed: J3.2, U2.12 (PA6)
unnamed: J3.3, U2.11 (PA5)
unnamed: J3.4, U2.10 (PA4)
unnamed: Q1.1 (G), R3.1
unnamed: Q1.2 (S), R4.2, U4.19 (~RTS)
unnamed: Q2.1 (G), R4.1
unnamed: Q2.2 (S), R3.2, U4.23 (~DTR)
unnamed: R7.1, U2.1 (BOOT0)
unnamed: R6.1, U2.4 (NRST)
unnamed: R1.2, U4.21 (TXD)
unnamed: R2.2, U4.9 (~RST)
STMRX: U1.16 (IO13), U2.18 (PA10)
STMTX: U1.7 (IO35), U2.17 (PA9)
SWDCLK: J4.2, U2.20 (PA14)
SWDIO: J4.1, U2.19 (PA13)
VIO: C3.1, C6.1, R2.1, U4.5 (VIO), U4.6 (VDD)

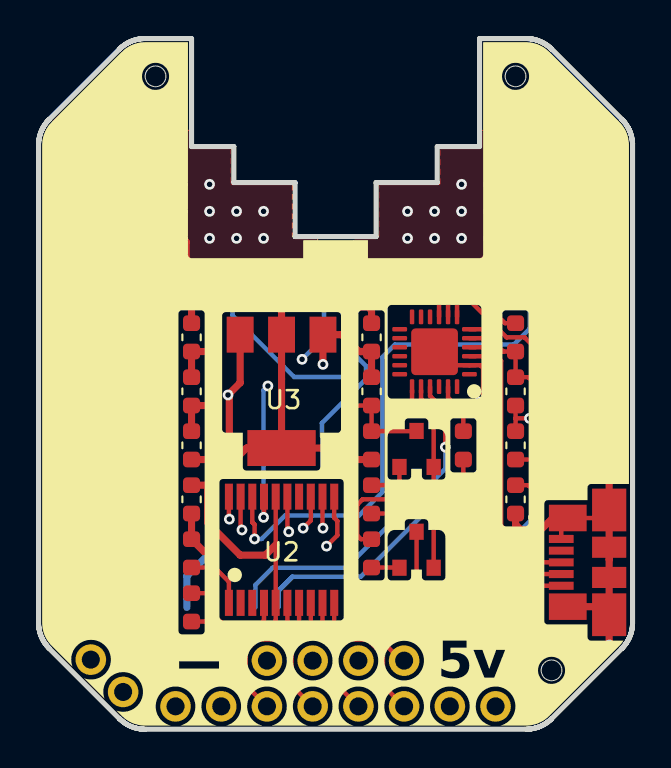
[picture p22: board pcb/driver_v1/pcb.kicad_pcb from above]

Board: 4 copper layers, 33.0 x 38.4 mm, 26 parts (1 on the bottom side), 31 nets.

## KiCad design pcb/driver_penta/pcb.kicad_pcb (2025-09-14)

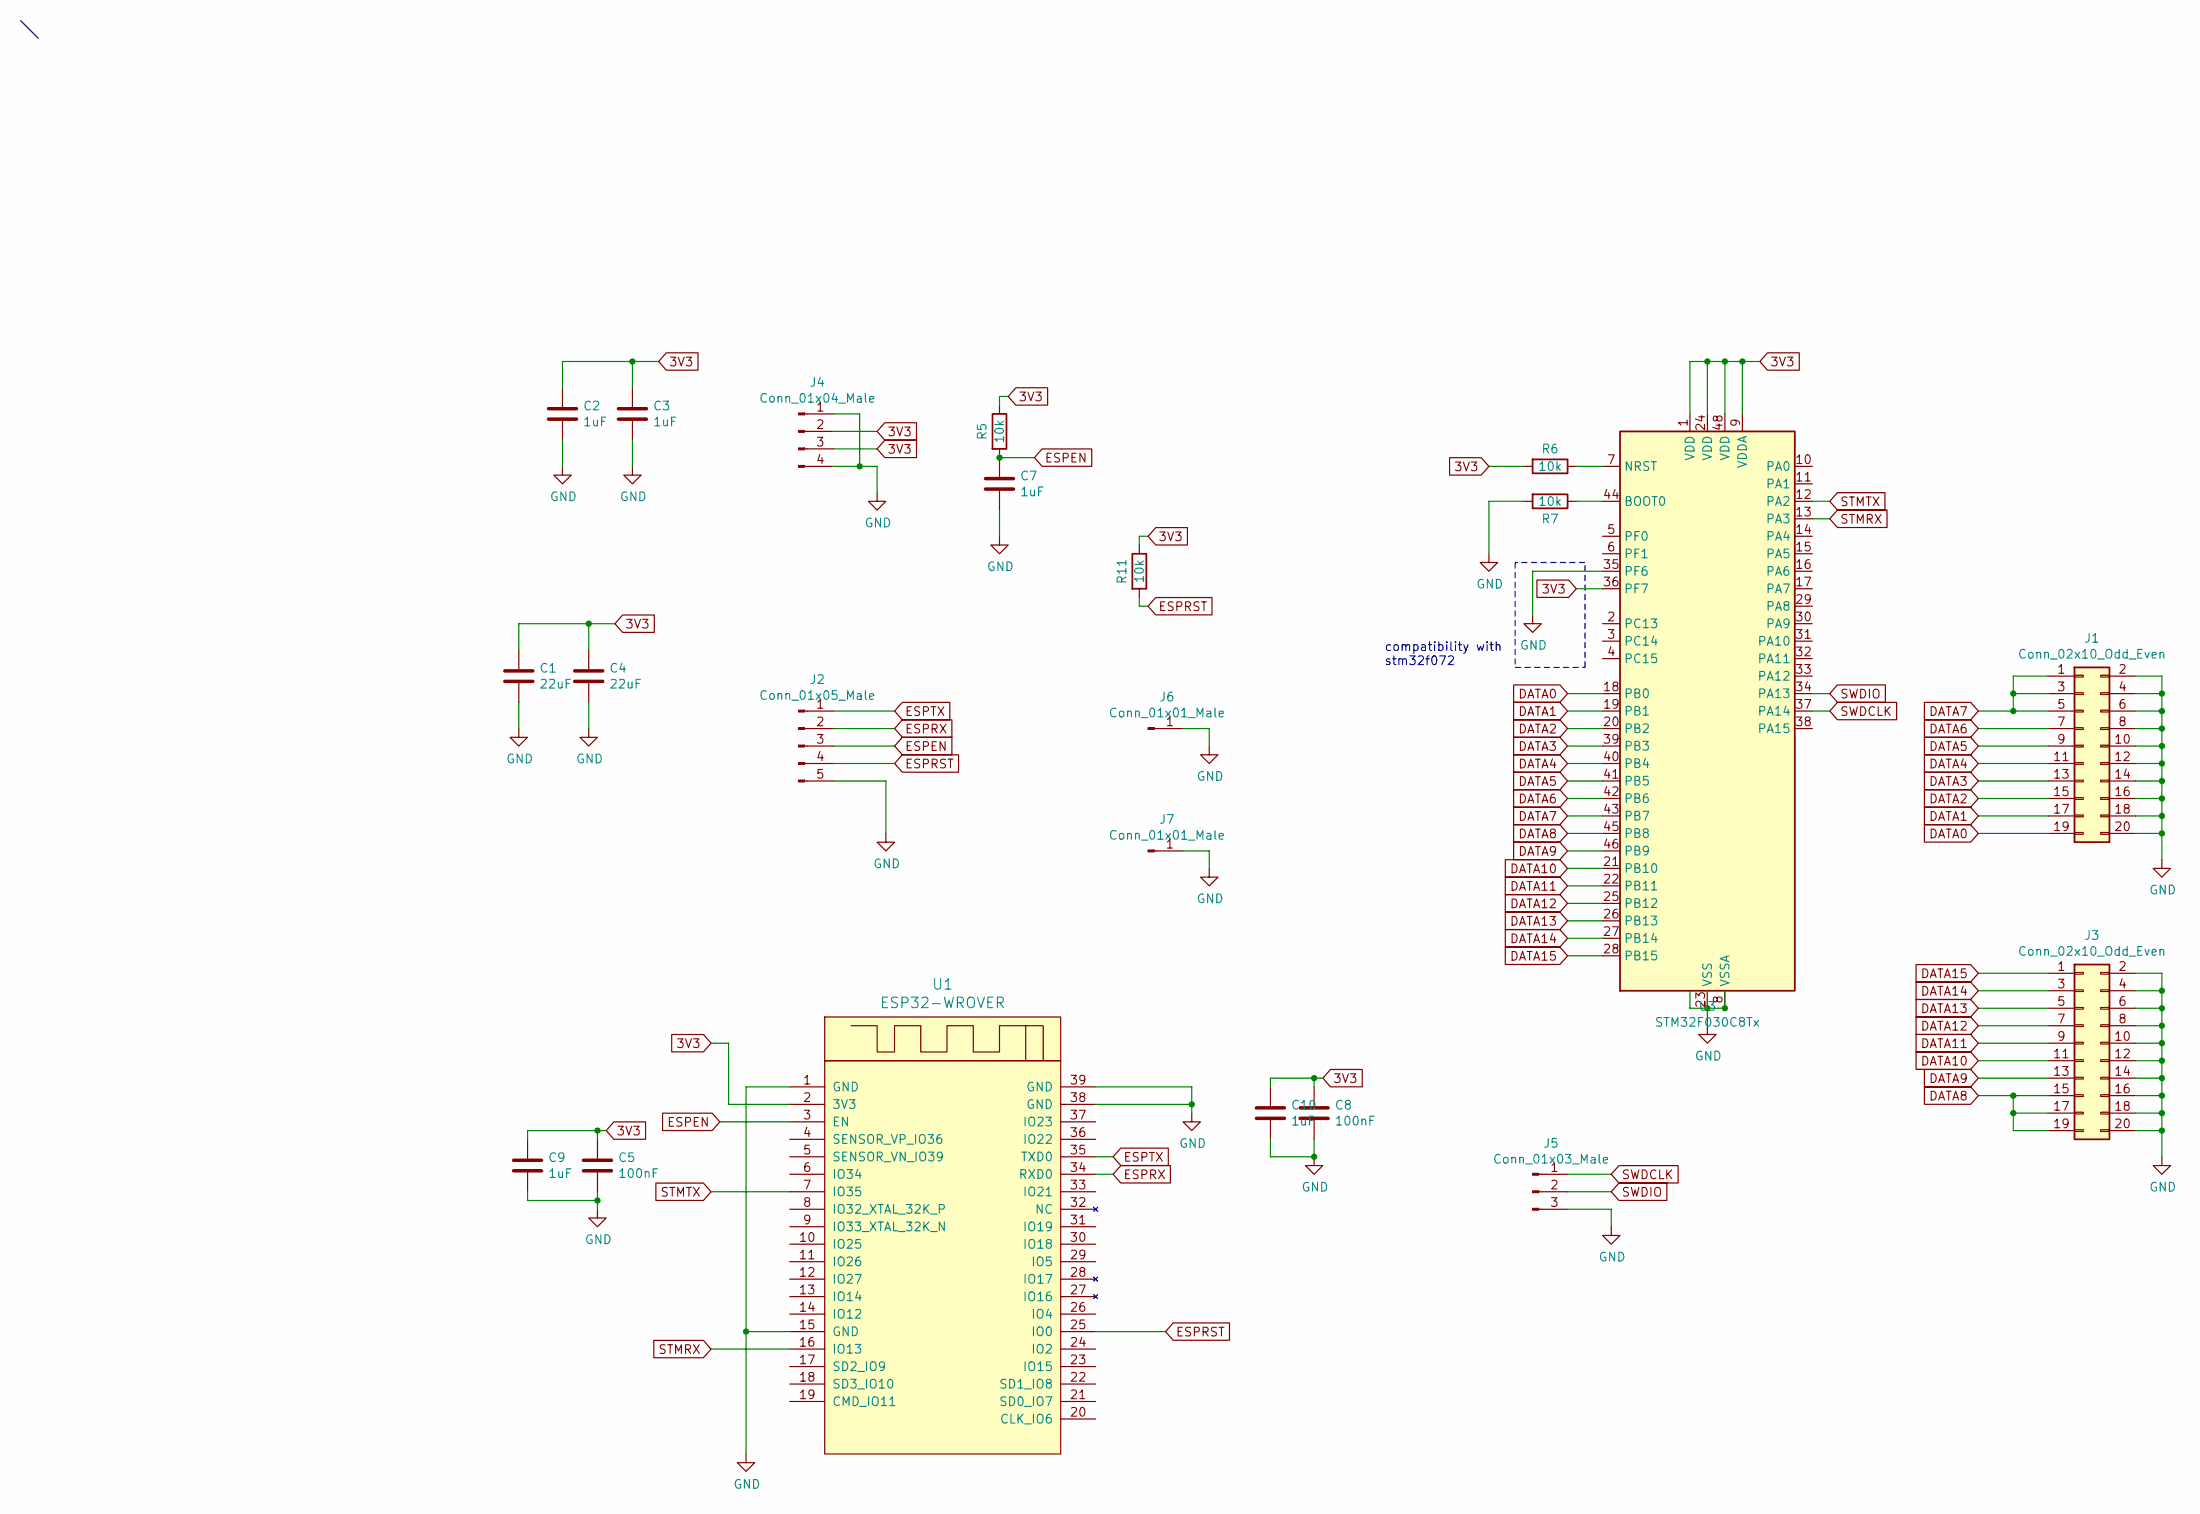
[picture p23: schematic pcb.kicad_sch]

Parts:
C1, C4: 22uF; C_1210_3225Metric; LCSC C52923
C2, C3, C7, C9, C10: 1uF; C_0402_1005Metric; LCSC C52923
C5, C8: 100nF; C_0402_1005Metric; LCSC C1525
J1, J3: Conn_02x10_Odd_Even; PinHeader_2x10_P2.54mm_Vertical
J2: Conn_01x05_Male; Molex_PicoBlade_53261-0571_1x05-1MP_P1.25mm_Horizontal; LCSC C225114
J4: Conn_01x04_Male; PinHeader_1x04_P2.54mm_Vertical
J5: Conn_01x03_Male; PinHeader_1x03_P2.54mm_Vertical
J6, J7: Conn_01x01_Male; PinHeader_1x01_P2.54mm_Vertical
R5, R6, R7, R11: 10k; R_0402_1005Metric; LCSC C25744
U1: ESP32-WROVER; XCVR_ESP32-WROVER; LCSC C701352
U3: STM32F030C8Tx; LQFP-48_7x7mm_P0.5mm; LCSC C23922

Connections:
3V3: C1.1, C2.1, C3.1, C4.1, C5.1, C8.1, C9.1, C10.1, J4.2, J4.3, R5.1, R6.2, R11.1, U1.2 (3V3), U3.1 (VDD), U3.9 (VDDA), U3.24 (VDD), U3.36 (PF7), U3.48 (VDD)
DATA0: J1.19, U3.18 (PB0)
DATA1: J1.17, U3.19 (PB1)
DATA2: J1.15, U3.20 (PB2)
DATA3: J1.13, U3.39 (PB3)
DATA4: J1.11, U3.40 (PB4)
DATA5: J1.9, U3.41 (PB5)
DATA6: J1.7, U3.42 (PB6)
DATA7: J1.1, J1.3, J1.5, U3.43 (PB7)
DATA8: J3.15, J3.17, J3.19, U3.45 (PB8)
DATA9: J3.13, U3.46 (PB9)
DATA10: J3.11, U3.21 (PB10)
DATA11: J3.9, U3.22 (PB11)
DATA12: J3.7, U3.25 (PB12)
DATA13: J3.5, U3.26 (PB13)
DATA14: J3.3, U3.27 (PB14)
DATA15: J3.1, U3.28 (PB15)
ESPEN: C7.1, J2.3, R5.2, U1.3 (EN)
ESPRST: J2.4, R11.2, U1.25 (IO0)
ESPRX: J2.2, U1.34 (RXD0)
ESPTX: J2.1, U1.35 (TXD0)
GND: C1.2, C2.2, C3.2, C4.2, C5.2, C7.2, C8.2, C9.2, C10.2, J1.2, J1.4, J1.6, J1.8, J1.10, J1.12, J1.14, J1.16, J1.18, J1.20, J2.5, J3.2, J3.4, J3.6, J3.8, J3.10, J3.12, J3.14, J3.16, J3.18, J3.20, J4.1, J4.4, J5.3, J6.1, J7.1, R7.2, U1.1 (GND), U1.15 (GND), U1.38 (GND), U1.39 (GND), U3.8 (VSSA), U3.23 (VSS), U3.35 (PF6), U3.47 (VSS)
unnamed: R7.1, U3.44 (BOOT0)
unnamed: R6.1, U3.7 (NRST)
STMRX: U1.16 (IO13), U3.13 (PA3)
STMTX: U1.7 (IO35), U3.12 (PA2)
SWDCLK: J5.1, U3.37 (PA14)
SWDIO: J5.2, U3.34 (PA13)

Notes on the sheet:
compatibility with stm32f072

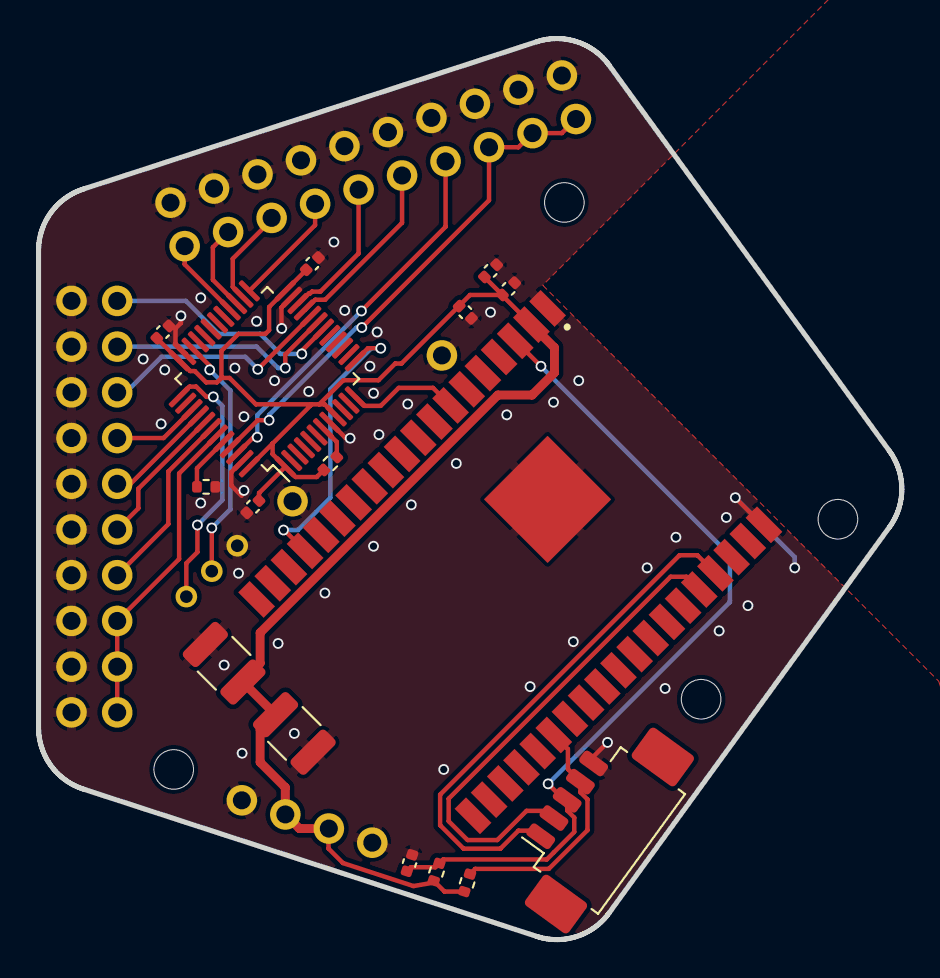
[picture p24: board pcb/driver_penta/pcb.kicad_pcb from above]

Board: 2 copper layers, 48.0 x 50.1 mm, 22 parts (0 on the bottom side), 28 nets.

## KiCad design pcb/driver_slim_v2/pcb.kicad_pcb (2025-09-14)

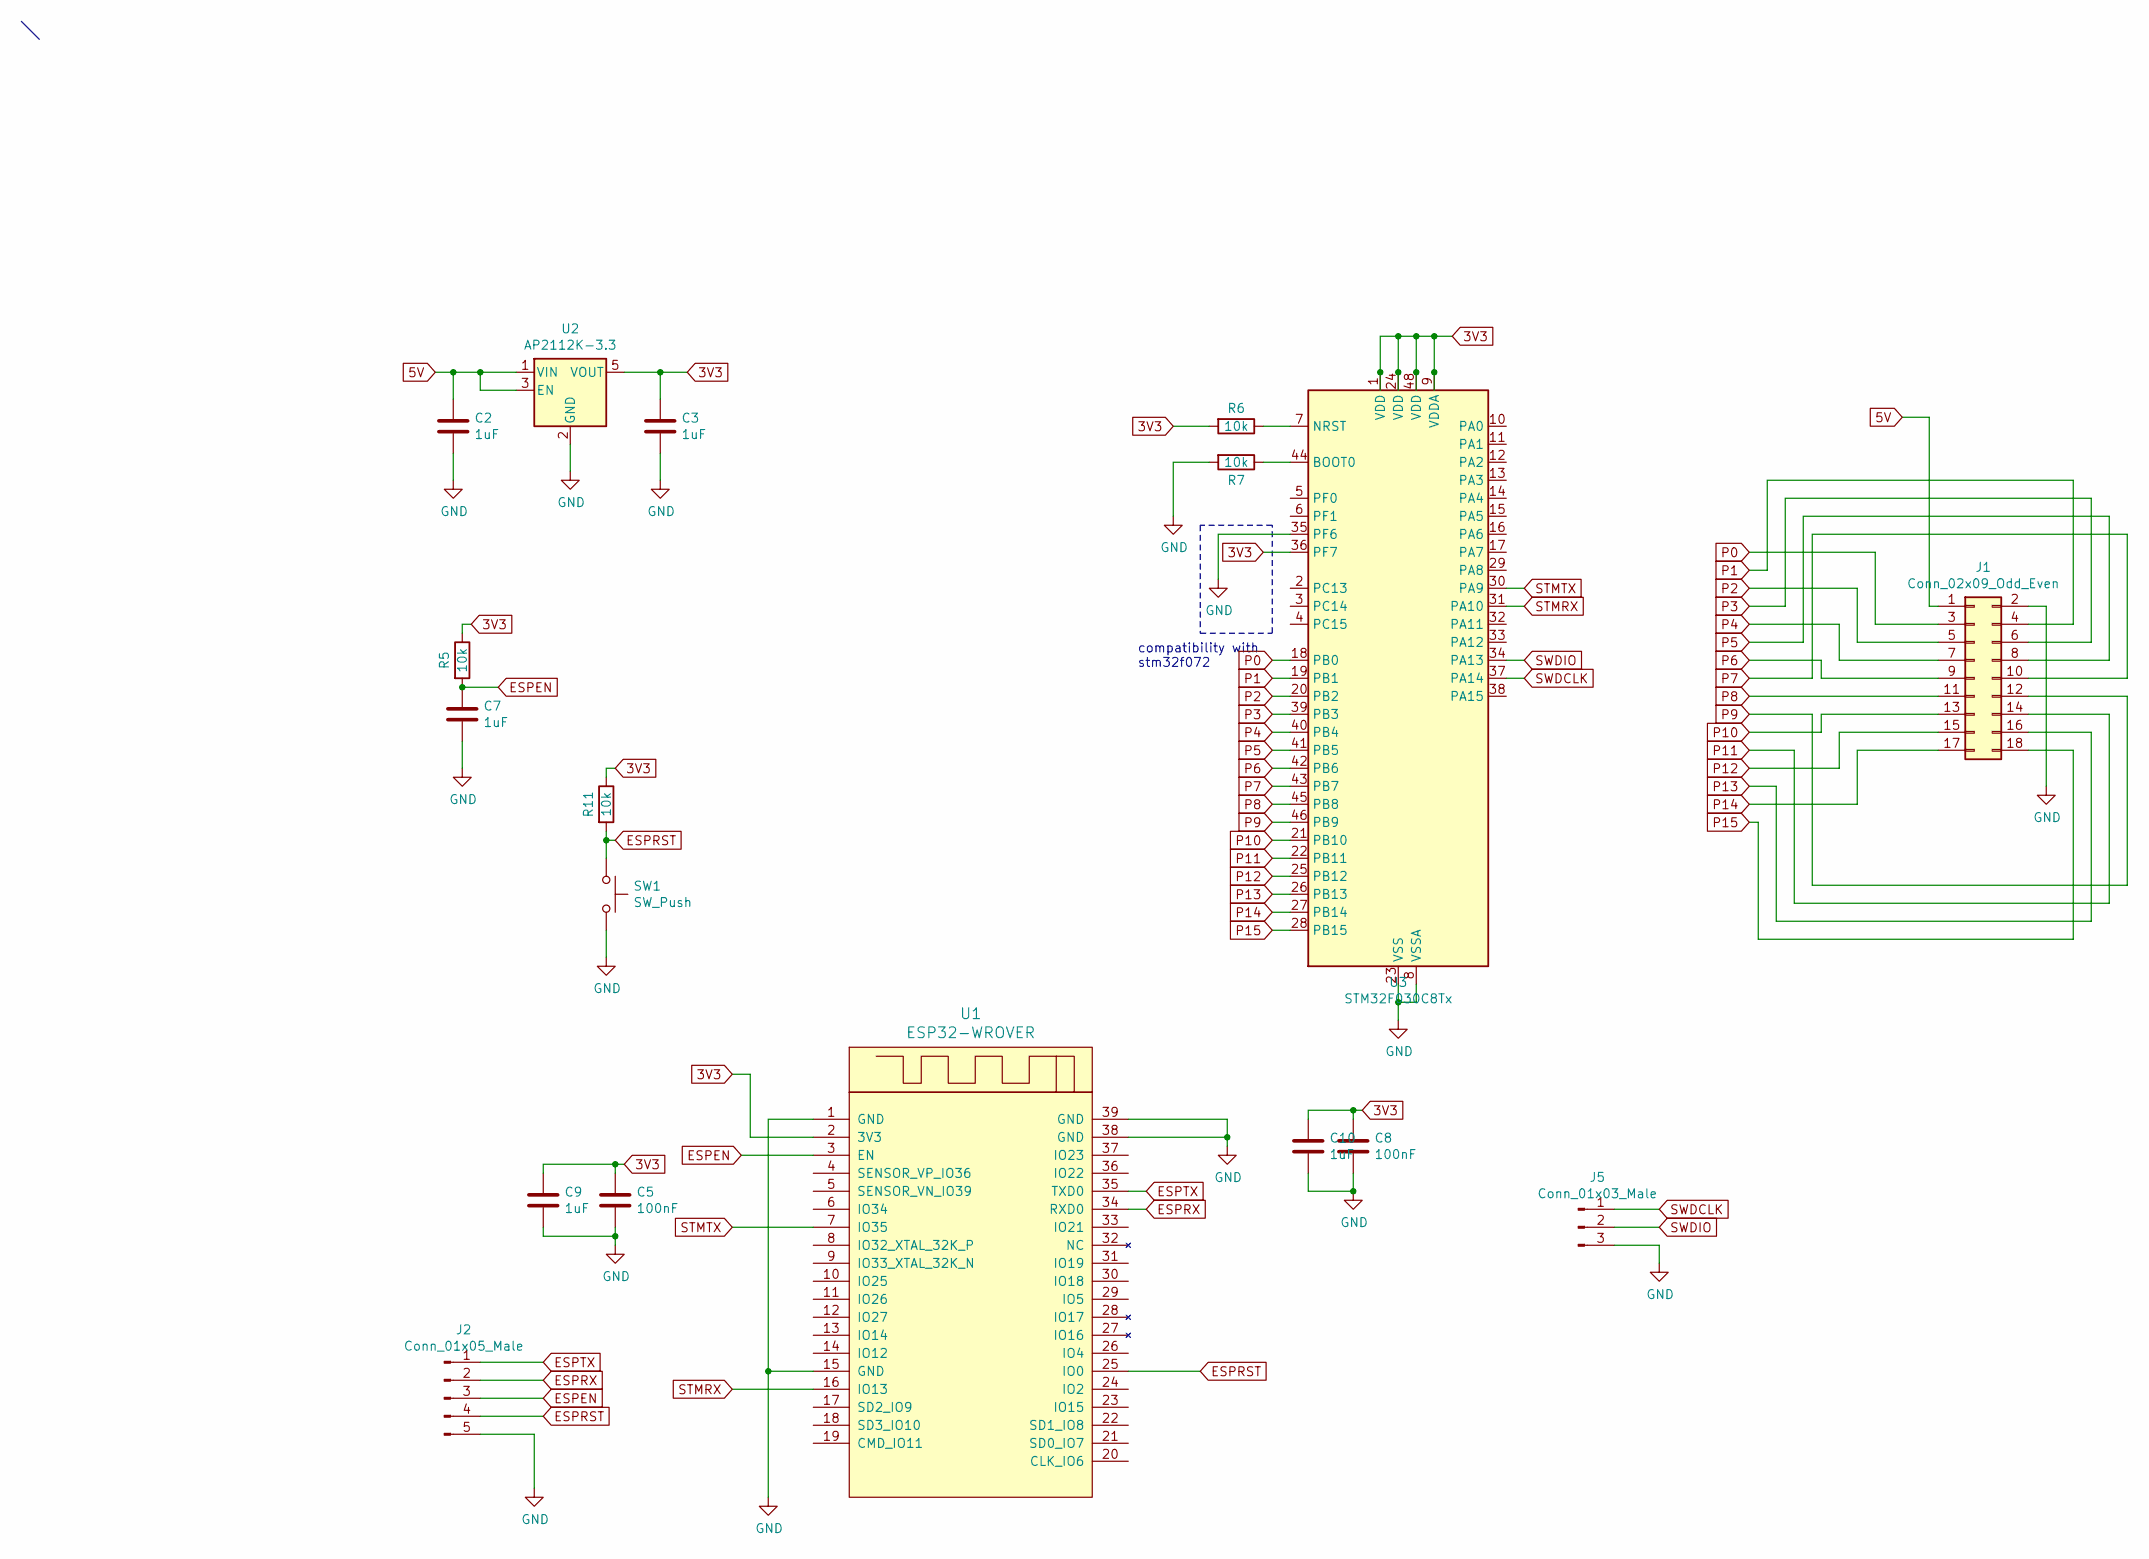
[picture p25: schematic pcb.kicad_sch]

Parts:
C2, C3, C7, C9, C10: 1uF; C_0402_1005Metric; LCSC C52923
C5, C8: 100nF; C_0402_1005Metric; LCSC C1525
J1: Conn_02x09_Odd_Even; PinHeader_2x09_P2.54mm_Vertical
J2: Conn_01x05_Male; Molex_PicoBlade_53261-0571_1x05-1MP_P1.25mm_Horizontal; LCSC C225114
J5: Conn_01x03_Male; PinHeader_1x03_P2.54mm_Vertical
R5, R6, R7, R11: 10k; R_0402_1005Metric; LCSC C25744
SW1: SW_Push; SW_Push_1P1T_NO_CK_KMR2
U1: ESP32-WROVER; XCVR_ESP32-WROVER; LCSC C701352
U2: AP2112K-3.3; SOT-23-5; LCSC C82942
U3: STM32F030C8Tx; LQFP-48_7x7mm_P0.5mm; LCSC C23922

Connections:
3V3: C3.1, C5.1, C8.1, C9.1, C10.1, R5.1, R6.2, R11.1, U1.2 (3V3), U2.5 (VOUT), U3.1 (VDD), U3.9 (VDDA), U3.24 (VDD), U3.36 (PF7), U3.48 (VDD)
5V: C2.1, J1.1, U2.1 (VIN), U2.3 (EN)
ESPEN: C7.1, J2.3, R5.2, U1.3 (EN)
ESPRST: J2.4, R11.2, SW1.1, U1.25 (IO0)
ESPRX: J2.2, U1.34 (RXD0)
ESPTX: J2.1, U1.35 (TXD0)
GND: C2.2, C3.2, C5.2, C7.2, C8.2, C9.2, C10.2, J1.2, J2.5, J5.3, R7.2, SW1.2, U1.1 (GND), U1.15 (GND), U1.38 (GND), U1.39 (GND), U2.2 (GND), U3.8 (VSSA), U3.23 (VSS), U3.35 (PF6), U3.47 (VSS)
unnamed: R7.1, U3.44 (BOOT0)
unnamed: R6.1, U3.7 (NRST)
P0: J1.3, U3.18 (PB0)
P1: J1.4, U3.19 (PB1)
P2: J1.5, U3.20 (PB2)
P3: J1.6, U3.39 (PB3)
P4: J1.7, U3.40 (PB4)
P5: J1.8, U3.41 (PB5)
P6: J1.9, U3.42 (PB6)
P7: J1.10, U3.43 (PB7)
P8: J1.11, U3.45 (PB8)
P9: J1.12, U3.46 (PB9)
P10: J1.13, U3.21 (PB10)
P11: J1.14, U3.22 (PB11)
P12: J1.15, U3.25 (PB12)
P13: J1.16, U3.26 (PB13)
P14: J1.17, U3.27 (PB14)
P15: J1.18, U3.28 (PB15)
STMRX: U1.16 (IO13), U3.31 (PA10)
STMTX: U1.7 (IO35), U3.30 (PA9)
SWDCLK: J5.1, U3.37 (PA14)
SWDIO: J5.2, U3.34 (PA13)

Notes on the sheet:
compatibility with stm32f072

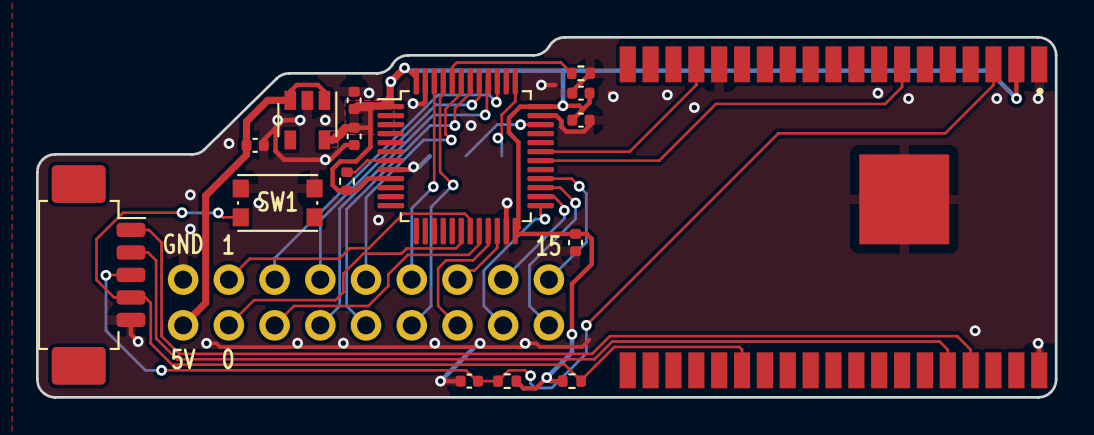
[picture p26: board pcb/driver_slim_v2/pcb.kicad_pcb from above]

Board: 2 copper layers, 56.6 x 20.0 mm, 18 parts (1 on the bottom side), 29 nets.

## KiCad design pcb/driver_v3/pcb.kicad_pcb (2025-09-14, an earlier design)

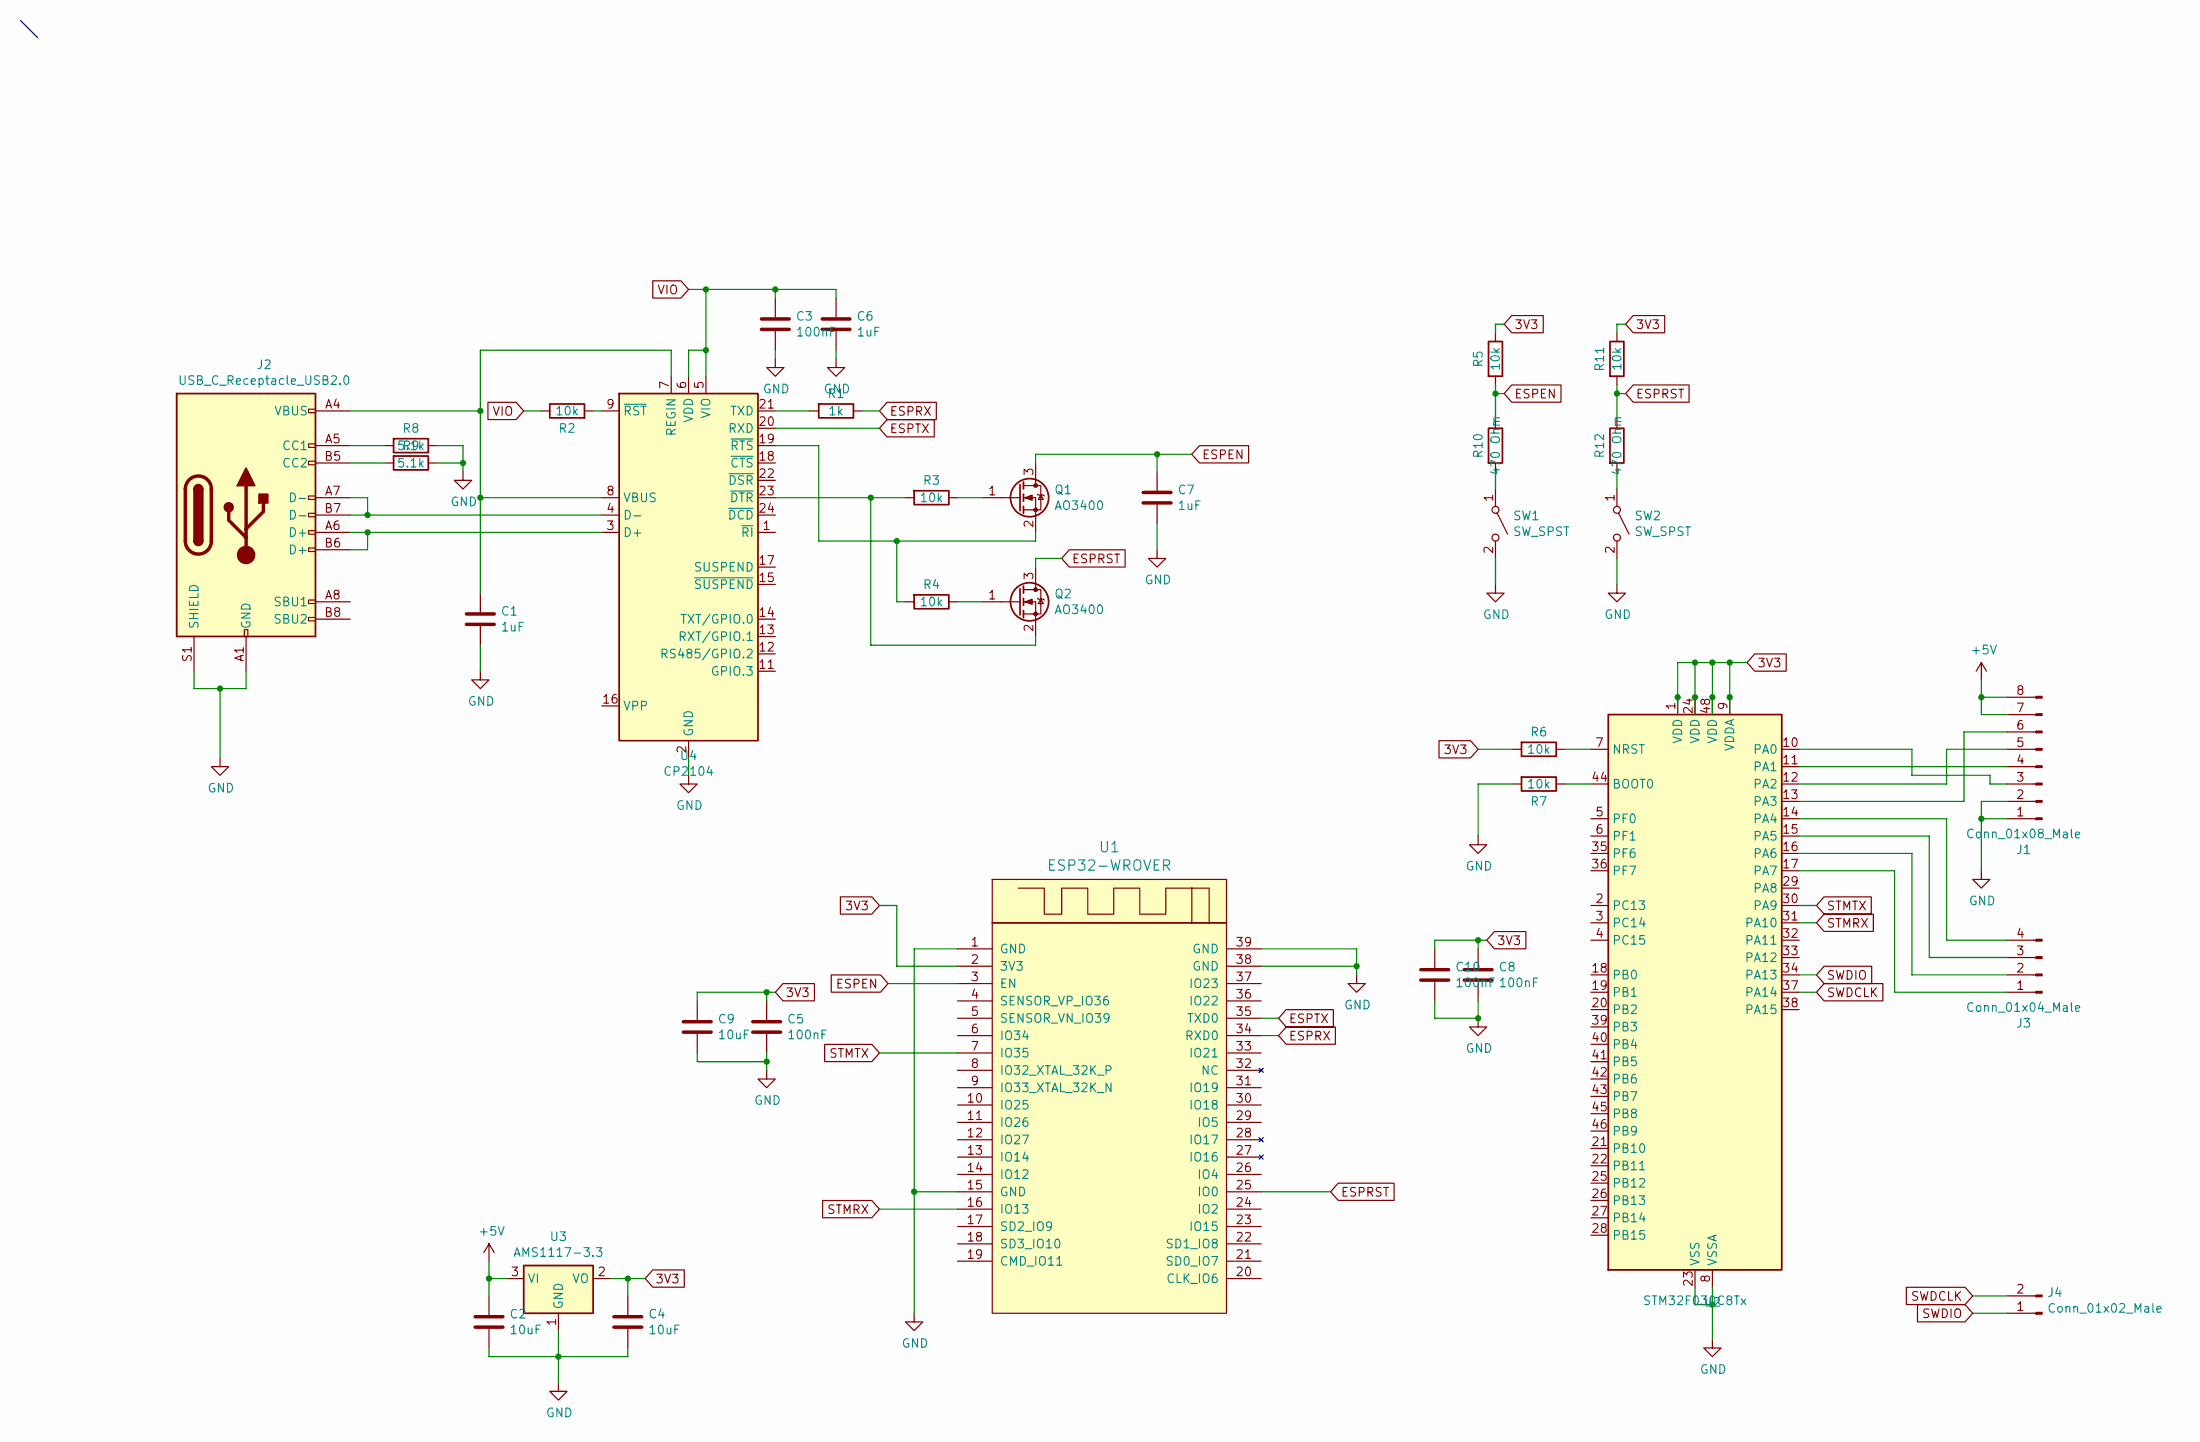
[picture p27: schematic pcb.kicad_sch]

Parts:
C1, C6, C7: 1uF; C_0402_1005Metric; LCSC C52923
C2, C4, C9: 10uF; C_0603_1608Metric; LCSC C19702
C3, C5, C8, C10: 100nF; C_0402_1005Metric; LCSC C1525
J1: Conn_01x08_Male; PinHeader_1x08_P2.54mm_Vertical
J2: USB_C_Receptacle_USB2.0; USB_C_Receptacle_HRO_TYPE-C-31-M-12
J3: Conn_01x04_Male; PinHeader_1x04_P2.54mm_Vertical
J4: Conn_01x02_Male; PinHeader_1x02_P2.54mm_Vertical
Q1, Q2: AO3400; SOT-23; LCSC C20917
R1: 1k; R_0402_1005Metric; LCSC C11702
R2, R3, R4, R5, R6, R7, R11: 10k; R_0402_1005Metric; LCSC C25744
R8, R9: 5.1k; R_0402_1005Metric; LCSC C25905
R10, R12: 470 Ohm; R_0402_1005Metric; LCSC C25792
SW1, SW2: SW_SPST; SW_SPST_B3U-1000P
U1: ESP32-WROVER; XCVR_ESP32-WROVER
U2: STM32F030C8Tx; LQFP-48_7x7mm_P0.5mm
U3: AMS1117-3.3; SOT-223-3_TabPin2; LCSC C6186
U4: CP2104; QFN-24-1EP_4x4mm_P0.5mm_EP2.6x2.6mm; LCSC C47742

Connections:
3V3: C4.1, C5.1, C8.1, C9.1, C10.1, R5.1, R6.2, R11.1, U1.2 (3V3), U2.1 (VDD), U2.9 (VDDA), U2.24 (VDD), U2.48 (VDD), U3.2 (VO)
+5V: C2.1, J1.7, J1.8, U3.3 (VI)
ESPEN: C7.1, Q1.3 (D), R5.2, R10.1, U1.3 (EN)
ESPRST: Q2.3 (D), R11.2, R12.1, U1.25 (IO0)
ESPRX: R1.1, U1.34 (RXD0)
ESPTX: U1.35 (TXD0), U4.20 (RXD)
GND: C1.2, C2.2, C3.2, C4.2, C5.2, C6.2, C7.2, C8.2, C9.2, C10.2, J1.1, J1.2, J2.A1 (GND), J2.A12 (GND), J2.B1 (GND), J2.B12 (GND), J2.S1 (SHIELD), R7.2, R8.1, R9.1, SW1.2 (B), SW2.2 (B), U1.1 (GND), U1.15 (GND), U1.38 (GND), U1.39 (GND), U2.8 (VSSA), U2.23 (VSS), U2.47 (VSS), U3.1 (GND), U4.2 (GND), U4.25 (GND)
unnamed: J1.3, U2.10 (PA0)
unnamed: J1.4, U2.11 (PA1)
unnamed: J1.5, U2.12 (PA2)
unnamed: J1.6, U2.13 (PA3)
unnamed: J2.A5 (CC1), R8.2
unnamed: J2.B5 (CC2), R9.2
unnamed: J3.1, U2.17 (PA7)
unnamed: J3.2, U2.16 (PA6)
unnamed: J3.3, U2.15 (PA5)
unnamed: J3.4, U2.14 (PA4)
unnamed: Q1.1 (G), R3.1
unnamed: Q1.2 (S), R4.2, U4.19 (~RTS)
unnamed: Q2.1 (G), R4.1
unnamed: Q2.2 (S), R3.2, U4.23 (~DTR)
unnamed: R10.2, SW1.1 (A)
unnamed: R12.2, SW2.1 (A)
unnamed: R7.1, U2.44 (BOOT0)
unnamed: R6.1, U2.7 (NRST)
unnamed: J2.A6 (D+), J2.B6 (D+), U4.3 (D+)
unnamed: J2.A7 (D-), J2.B7 (D-), U4.4 (D-)
unnamed: C1.1, J2.A4 (VBUS), J2.A9 (VBUS), J2.B4 (VBUS), J2.B9 (VBUS), U4.7 (REGIN), U4.8 (VBUS)
unnamed: R1.2, U4.21 (TXD)
unnamed: R2.2, U4.9 (~RST)
STMRX: U1.16 (IO13), U2.31 (PA10)
STMTX: U1.7 (IO35), U2.30 (PA9)
SWDCLK: J4.2, U2.37 (PA14)
SWDIO: J4.1, U2.34 (PA13)
VIO: C3.1, C6.1, R2.1, U4.5 (VIO), U4.6 (VDD)

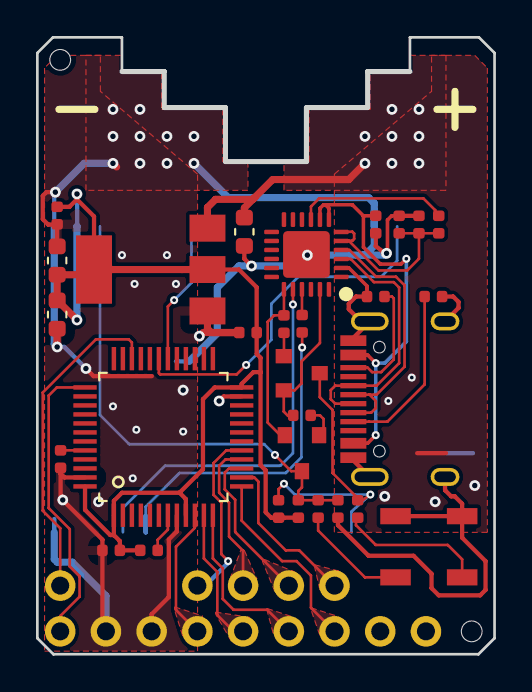
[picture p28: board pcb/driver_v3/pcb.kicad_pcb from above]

Board: 4 copper layers, 25.4 x 34.3 mm, 34 parts (1 on the bottom side), 35 nets.

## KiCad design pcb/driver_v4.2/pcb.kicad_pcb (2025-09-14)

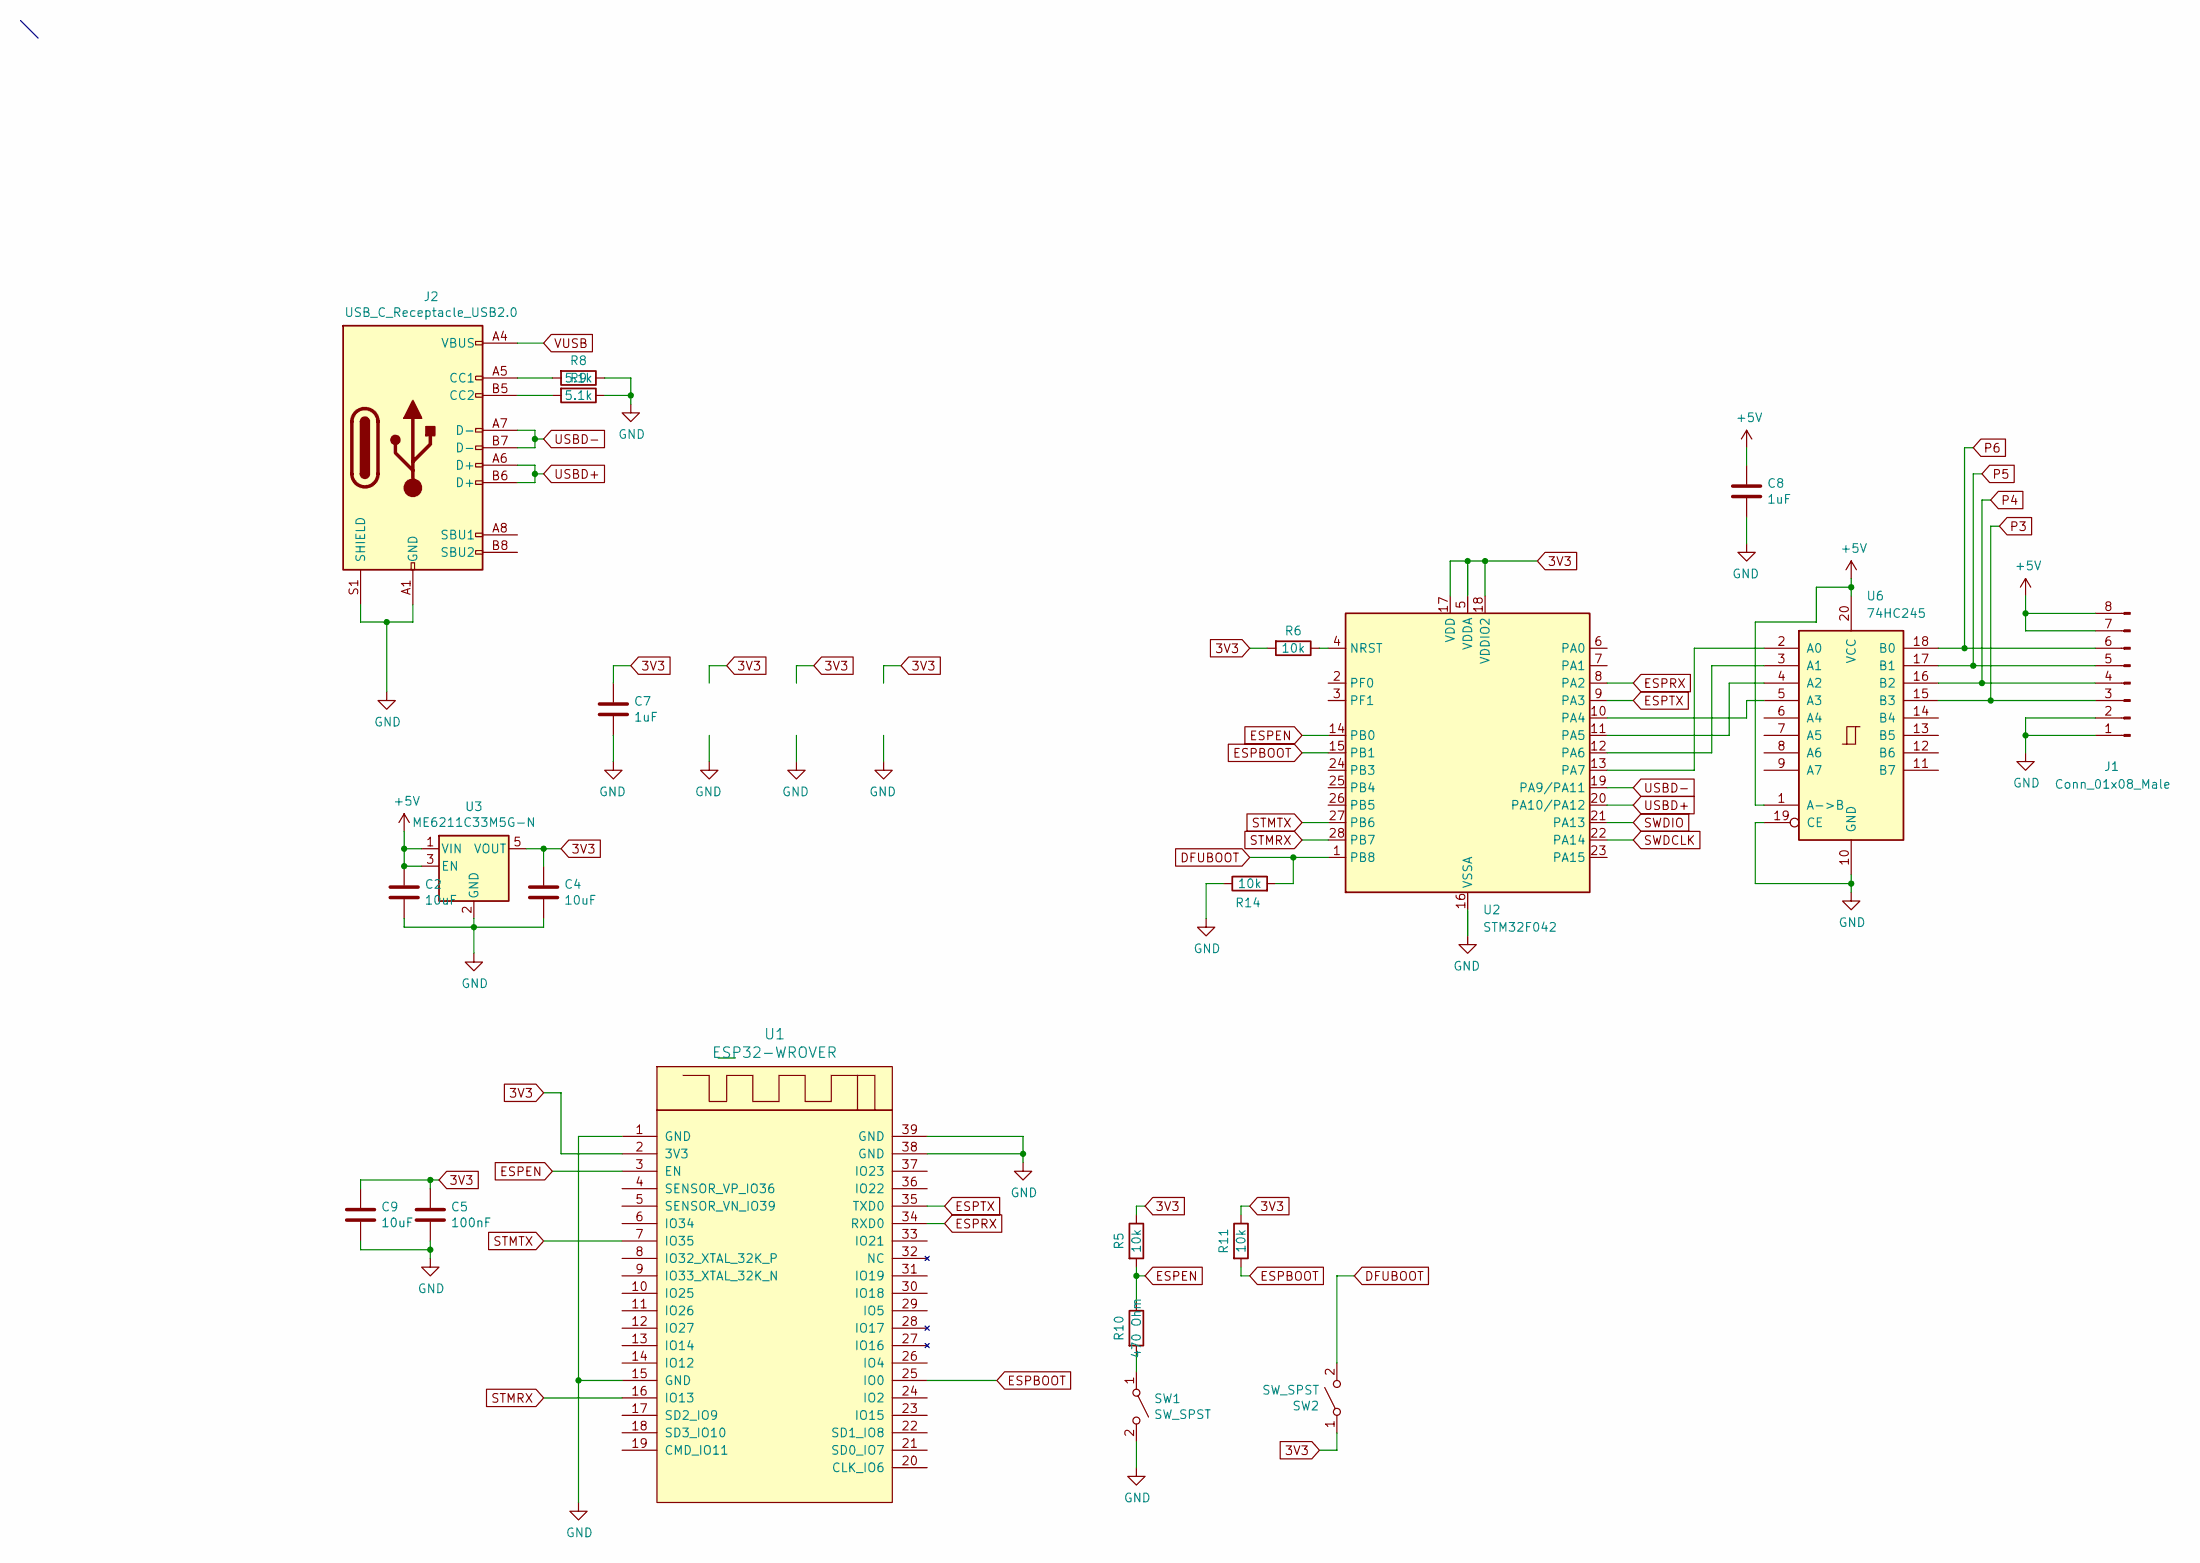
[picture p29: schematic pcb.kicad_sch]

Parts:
C2, C4, C9: 10uF; C_0603_1608Metric; LCSC C19702
C5: 100nF; C_0402_1005Metric; LCSC C1525
C7, C8: 1uF; C_0402_1005Metric; LCSC C52923
J1: Conn_01x08_Male; PinHeader_1x08_P2.54mm_Vertical
J2: USB_C_Receptacle_USB2.0; USB_C_Receptacle_HRO_TYPE-C-31-M-12; LCSC C165948
R5, R6, R11, R14: 10k; R_0402_1005Metric; LCSC C25744
R8, R9: 5.1k; R_0402_1005Metric; LCSC C25905
R10: 470 Ohm; R_0402_1005Metric; LCSC C25117
SW1, SW2: SW_SPST; SW_Push_1P1T_NO_CK_KMR2; LCSC C318893
U1: ESP32-WROVER; XCVR_ESP32-WROVER
U2: STM32F042; QFN-28_4x4mm_P0.5mm
U3: ME6211C33M5G-N; SOT-23-5; LCSC C82942
U6: 74HC245; DHVQFN-20-1EP_2.5x4.5mm_P0.5mm_EP1x3mm

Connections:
3V3: C4.1, C5.1, C7.1, C9.1, R5.1, R6.2, R11.1, SW2.1 (A), U1.2 (3V3), U2.5 (VDDA), U2.17 (VDD), U2.18 (VDDIO2), U3.5 (VOUT)
+5V: C2.1, C8.1, J1.7, J1.8, U3.1 (VIN), U3.3 (EN), U6.1 (A->B), U6.20 (VCC)
DFUBOOT: R14.2, SW2.2 (B), U2.1 (PB8)
ESPBOOT: R11.2, U1.25 (IO0), U2.15 (PB1)
ESPEN: R5.2, R10.1, U1.3 (EN), U2.14 (PB0)
ESPRX: U1.34 (RXD0), U2.8 (PA2)
ESPTX: U1.35 (TXD0), U2.9 (PA3)
GND: C2.2, C4.2, C5.2, C7.2, C8.2, C9.2, J1.1, J1.2, J2.A1 (GND), J2.A12 (GND), J2.B1 (GND), J2.B12 (GND), J2.S1 (SHIELD), R8.1, R9.1, R14.1, SW1.2 (B), U1.1 (GND), U1.15 (GND), U1.38 (GND), U1.39 (GND), U2.16 (VSSA), U3.2 (GND), U6.10 (GND), U6.19 (CE)
unnamed: J2.A5 (CC1), R8.2
unnamed: J2.B5 (CC2), R9.2
unnamed: R10.2, SW1.1 (A)
unnamed: R6.1, U2.4 (NRST)
unnamed: U2.10 (PA4), U6.5 (A3)
unnamed: U2.11 (PA5), U6.4 (A2)
unnamed: U2.12 (PA6), U6.3 (A1)
unnamed: U2.13 (PA7), U6.2 (A0)
P3: J1.3, U6.15 (B3)
P4: J1.4, U6.16 (B2)
P5: J1.5, U6.17 (B1)
P6: J1.6, U6.18 (B0)
STMRX: U1.16 (IO13), U2.28 (PB7)
STMTX: U1.7 (IO35), U2.27 (PB6)
SWDCLK: U2.22 (PA14)
SWDIO: U2.21 (PA13)
USBD+: J2.A6 (D+), J2.B6 (D+), U2.20 (PA10/PA12)
USBD-: J2.A7 (D-), J2.B7 (D-), U2.19 (PA9/PA11)
VUSB: J2.A4 (VBUS), J2.A9 (VBUS), J2.B4 (VBUS), J2.B9 (VBUS)

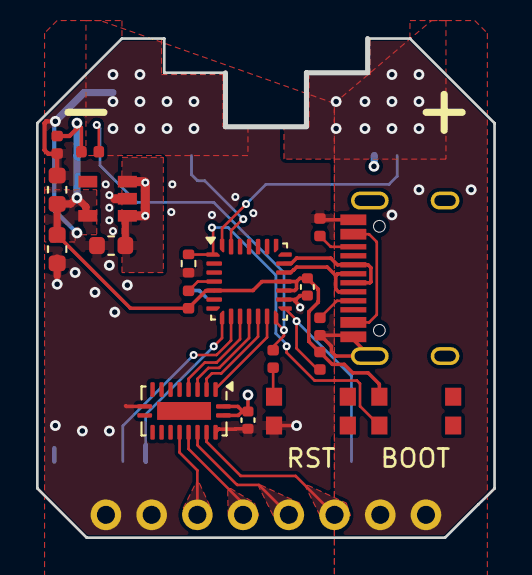
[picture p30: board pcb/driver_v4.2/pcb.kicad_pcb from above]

Board: 4 copper layers, 25.4 x 27.7 mm, 21 parts (1 on the bottom side), 25 nets.

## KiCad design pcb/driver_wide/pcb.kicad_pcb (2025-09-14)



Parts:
C2, C4, C9: 10uF; C_0603_1608Metric; LCSC C19702
C3, C5, C8, C10: 100nF; C_0402_1005Metric; LCSC C1525
C6: 1uF; C_0402_1005Metric; LCSC C52923
C11, C12, C13, C14: 100nF; C_0402_1005Metric; LCSC C19702
J1, J3, J5: Conn_01x16_Male; PinHeader_1x16_P2.54mm_Vertical
J2: USB_C_Receptacle_USB2.0; USB_C_Receptacle_HRO_TYPE-C-31-M-12; LCSC C165948
J4: Conn_01x03_Male; PinHeader_1x03_P2.54mm_Vertical
J6: Conn_01x02_Male; PinHeader_1x02_P2.54mm_Vertical
J7: Conn_01x01_Male; PinHeader_1x01_P2.54mm_Vertical
JP1: Jumper_2_Bridged; SolderJumper-2_P1.3mm_Bridged_Pad1.0x1.5mm
JP2: Jumper_2_Open; SolderJumper-2_P1.3mm_Open_Pad1.0x1.5mm
R1, R2, R6, R7: 10k; R_0402_1005Metric; LCSC C25744
R3, R4, R13, R14, R15, R16, R17, R18, R19, R20, R21, R22, R23, R24, R25, R26, R27, R28, R29, R30, R31, R32, R33, R34, R35, R36, R37, R38, R39, R40, R41, R42: 68 Ohm; R_0402_1005Metric; LCSC C25744
R8, R9: 5.1k; R_0402_1005Metric; LCSC C25905
SW1, SW2: SW_SPST; SW_Push_1P1T_NO_CK_KMR2; LCSC C318893
U1: ESP32-WROVER; XCVR_ESP32-WROVER
U2: STM32F030CCTx; LQFP-48_7x7mm_P0.5mm
U3: ME6211C33M5G-N; SOT-23-5; LCSC C82942
U4: STM32F042F4Px; TSSOP-20_4.4x6.5mm_P0.65mm
U5, U6, U7, U8: 74HC245; TSSOP-20_4.4x6.5mm_P0.65mm

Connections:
3V3: C3.1, C4.1, C5.1, C6.1, C8.1, C9.1, C10.1, JP2.1 (A), R6.2, SW1.1 (A), SW2.2 (B), U1.2 (3V3), U2.1 (VDD), U2.9 (VDDA), U2.24 (VDD), U2.36 (VDD), U2.48 (VDD), U3.5 (VOUT), U4.4 (NRST), U4.5 (VDDA), U4.16 (VDD)
5V: C2.1, J2.A4 (VBUS), J2.A9 (VBUS), J2.B4 (VBUS), J2.B9 (VBUS), J6.2, JP1.1 (A), U3.1 (VIN), U3.3 (EN)
BOOT_DFU: J7.1, U4.1 (PB8)
BTN_BOOT: R1.1, SW2.1 (A), U4.11 (PA5)
BTN_RESET: R2.1, SW1.2 (B), U4.10 (PA4)
ESPEN: U1.3 (EN), U4.2 (PF0)
ESPRX: U1.34 (RXD0), U4.9 (PA3)
ESPTX: U1.35 (TXD0), U4.8 (PA2)
ESP_GPIO0: U1.25 (IO0), U4.3 (PF1)
GND: C2.2, C3.2, C4.2, C5.2, C6.2, C8.2, C9.2, C10.2, C11.2, C12.2, C13.2, C14.2, J1.1, J1.2, J1.3, J1.4, J1.5, J1.6, J1.7, J1.8, J1.9, J1.10, J1.11, J1.12, J1.13, J1.14, J1.15, J1.16, J2.A1 (GND), J2.A12 (GND), J2.B1 (GND), J2.B12 (GND), J2.S1 (SHIELD), J4.1, J6.1, R1.2, R2.2, R7.2, R8.1, R9.1, U1.1 (GND), U1.15 (GND), U1.38 (GND), U1.39 (GND), U2.8 (VSSA), U2.23 (VSS), U2.35 (VSS), U2.47 (VSS), U3.2 (GND), U4.15 (VSSA), U5.10 (GND), U5.19 (CE), U6.10 (GND), U6.19 (CE), U7.10 (GND), U7.19 (CE), U8.10 (GND), U8.19 (CE)
unnamed: J2.A5 (CC1), R8.2
unnamed: J2.B5 (CC2), R9.2
unnamed: R7.1, U2.44 (BOOT0)
unnamed: R6.1, U2.7 (NRST)
unnamed: R3.2, U5.18 (B0)
unnamed: R4.2, U5.17 (B1)
unnamed: R13.2, U5.16 (B2)
unnamed: R14.2, U5.15 (B3)
unnamed: R15.2, U5.14 (B4)
unnamed: R16.2, U5.13 (B5)
unnamed: R17.2, U5.12 (B6)
unnamed: R18.2, U5.11 (B7)
unnamed: R19.2, U6.18 (B0)
unnamed: R20.2, U6.17 (B1)
unnamed: R21.2, U6.16 (B2)
unnamed: R22.2, U6.15 (B3)
unnamed: R23.2, U6.14 (B4)
unnamed: R24.2, U6.13 (B5)
unnamed: R25.2, U6.12 (B6)
unnamed: R26.2, U6.11 (B7)
unnamed: R27.2, U7.18 (B0)
unnamed: R28.2, U7.17 (B1)
unnamed: R29.2, U7.16 (B2)
unnamed: R30.2, U7.15 (B3)
unnamed: R31.2, U7.14 (B4)
unnamed: R32.2, U7.13 (B5)
unnamed: R33.2, U7.12 (B6)
unnamed: R34.2, U7.11 (B7)
unnamed: R35.2, U8.18 (B0)
unnamed: R36.2, U8.17 (B1)
unnamed: R37.2, U8.16 (B2)
unnamed: R38.2, U8.15 (B3)
unnamed: R39.2, U8.14 (B4)
unnamed: R40.2, U8.13 (B5)
unnamed: R41.2, U8.12 (B6)
unnamed: R42.2, U8.11 (B7)
STMRX: U1.16 (IO13), U2.13 (PA3)
STMTX: U1.7 (IO35), U2.12 (PA2)
SWDCLK: J4.3, U2.37 (PA14)
SWDIO: J4.2, U2.34 (PA13)
VDATA: C11.1, C12.1, C13.1, C14.1, JP1.2 (B), JP2.2 (B), U5.1 (A->B), U5.20 (VCC), U6.1 (A->B), U6.20 (VCC), U7.1 (A->B), U7.20 (VCC), U8.1 (A->B), U8.20 (VCC)
clk0: J5.1, R18.1
clk0..3: U2.15 (PA5), U5.3 (A1), U5.5 (A3), U5.7 (A5), U5.9 (A7)
clk1: J5.2, R16.1
clk2: J5.3, R14.1
clk3: J5.4, R4.1
clk4: J5.5, R26.1
clk4..7: U2.16 (PA6), U6.3 (A1), U6.5 (A3), U6.7 (A5), U6.9 (A7)
clk5: J5.6, R24.1
clk6: J5.7, R22.1
clk7: J5.8, R20.1
clk8: J5.9, R34.1
clk8..11: U2.17 (PA7), U7.3 (A1), U7.5 (A3), U7.7 (A5), U7.9 (A7)
clk9: J5.10, R32.1
clk10: J5.11, R30.1
clk11: J5.12, R28.1
clk12: J5.13, R42.1
clk12..15: U2.30 (PA9), U8.3 (A1), U8.5 (A3), U8.7 (A5), U8.9 (A7)
clk13: J5.14, R40.1
clk14: J5.15, R38.1
clk15: J5.16, R36.1
data0: U2.18 (PB0), U5.8 (A6)
data1: U2.19 (PB1), U5.6 (A4)
data2: U2.20 (PB2), U5.4 (A2)
data3: U2.39 (PB3), U5.2 (A0)
data4: U2.40 (PB4), U6.8 (A6)
data5: U2.41 (PB5), U6.6 (A4)
data6: U2.42 (PB6), U6.4 (A2)
data7: U2.43 (PB7), U6.2 (A0)
data8: U2.45 (PB8), U7.8 (A6)
data9: U2.46 (PB9), U7.6 (A4)
data10: U2.21 (PB10), U7.4 (A2)
data11: U2.22 (PB11), U7.2 (A0)
data12: U2.25 (PB12), U8.8 (A6)
data13: U2.26 (PB13), U8.6 (A4)
data14: U2.27 (PB14), U8.4 (A2)
data15: U2.28 (PB15), U8.2 (A0)
dm: J2.A7 (D-), J2.B7 (D-), U4.17 (PA9/PA11)
dp: J2.A6 (D+), J2.B6 (D+), U4.18 (PA10/PA12)
out0: J3.1, R17.1
out1: J3.2, R15.1
out2: J3.3, R13.1
out3: J3.4, R3.1
out4: J3.5, R25.1
out5: J3.6, R23.1
out6: J3.7, R21.1
out7: J3.8, R19.1
out8: J3.9, R33.1
out9: J3.10, R31.1
out10: J3.11, R29.1
out11: J3.12, R27.1
out12: J3.13, R41.1
out13: J3.14, R39.1
out14: J3.15, R37.1
out15: J3.16, R35.1


Board: 2 copper layers, 60.0 x 50.0 mm, 69 parts (0 on the bottom side), 105 nets.

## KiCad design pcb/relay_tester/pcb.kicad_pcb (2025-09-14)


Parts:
C1: 1uF; C_0603_1608Metric_Pad1.08x0.95mm_HandSolder; LCSC C52923
C2, C3, C4, C5, C6, C7, C10: 100nF; C_0603_1608Metric_Pad1.08x0.95mm_HandSolder; LCSC C1525
C8, C9: 10uF; C_0603_1608Metric_Pad1.08x0.95mm_HandSolder; LCSC C19702
C11, C12: 14pF; C_0603_1608Metric_Pad1.08x0.95mm_HandSolder; LCSC C19702
D1, D2, D3, D4: WS2812B; LED_WS2812B_PLCC4_5.0x5.0mm_P3.2mm
J1: USB_C_Receptacle_USB2.0; USB_C_Receptacle_HRO_TYPE-C-31-M-12
J2: Conn_01x03_Male; PinHeader_1x03_P2.54mm_Vertical
J3: Conn_01x08_Male; padauk_test_a
J4, J5, J6, J7: Conn_01x04_Male; PinHeader_1x04_P2.54mm_Vertical
R1, R4, R6, R9: 100k; R_0603_1608Metric_Pad0.98x0.95mm_HandSolder; LCSC C11702
R2, R3: 5.1k; R_0603_1608Metric_Pad0.98x0.95mm_HandSolder; LCSC C25905
R5: 1k; R_0603_1608Metric_Pad0.98x0.95mm_HandSolder; LCSC C11702
R7, R8: 10k; R_0603_1608Metric_Pad0.98x0.95mm_HandSolder; LCSC C25744
U1: CH340B; SOIC-16_3.9x9.9mm_P1.27mm
U2: AP2204K-3.3; SOT-23-5
U3: STM32F030F4Px; TSSOP-20_4.4x6.5mm_P0.65mm
Y1: Crystal_GND24; TSX-3225

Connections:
3V3: C9.1, C10.1, R7.2, U2.5 (VOUT), U3.5 (VDDA), U3.16 (VDD)
GND: C1.2, C2.2, C3.2, C4.2, C5.2, C6.2, C7.2, C8.2, C9.2, C10.2, C11.2, C12.2, D1.3 (VSS), D2.3 (VSS), D3.3 (VSS), D4.3 (VSS), J1.A1 (GND), J1.A12 (GND), J1.B1 (GND), J1.B12 (GND), J1.S1 (SHIELD), J2.1, J3.7, J3.8, R1.1, R2.1, R3.1, R4.1, R6.1, R8.2, R9.1, U1.1 (GND), U2.2 (GND), U3.15 (VSS), Y1.2, Y1.4
LED_A: D1.4 (DIN), J3.1, R1.2, U3.10 (PA4)
LED_B: D2.4 (DIN), J3.2, R4.2, U3.11 (PA5)
LED_C: D3.4 (DIN), J3.3, R6.2, U3.12 (PA6)
LED_D: D4.4 (DIN), J3.4, R9.2, U3.13 (PA7)
unnamed: J1.A5 (CC1), R2.2
unnamed: J1.B5 (CC2), R3.2
unnamed: R5.2, U1.2 (TXD)
unnamed: J1.A6 (D+), J1.B6 (D+), U1.5 (UD+)
unnamed: J1.A7 (D-), J1.B7 (D-), U1.6 (UD-)
unnamed: C4.1, U1.4 (V3)
unnamed: R8.1, U3.1 (BOOT0)
unnamed: R7.1, U3.4 (NRST)
unnamed: C11.1, U3.2 (PF0), Y1.1
unnamed: C12.1, U3.3 (PF1), Y1.3
STMRX: R5.1, U3.18 (PA10)
STMTX: U1.3 (RXD), U3.17 (PA9)
SWDCLK: J2.2, U3.20 (PA14)
SWDIO: J2.3, U3.19 (PA13)
VUSB: C1.1, C2.1, C3.1, C5.1, C6.1, C7.1, C8.1, D1.1 (VDD), D2.1 (VDD), D3.1 (VDD), D4.1 (VDD), J1.A4 (VBUS), J1.A9 (VBUS), J1.B4 (VBUS), J1.B9 (VBUS), J3.5, J3.6, U1.16 (VCC), U2.1 (VIN), U2.3 (EN)

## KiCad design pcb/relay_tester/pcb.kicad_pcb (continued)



Board: 2 copper layers, 36.8 x 64.5 mm, 36 parts (22 on the bottom side), 21 nets.

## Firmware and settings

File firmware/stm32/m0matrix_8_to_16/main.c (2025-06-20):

/* Joining the FPGA cult next project, I promise */

#include <stdlib.h>
#include "stm32f0xx.h"

#include "bitbang.h"
#include "util.h"

#define CHANNEL_OFFSET (4)
/* with interleaving for speedy computation of bitbang buffers */
#define I(n) ( (n&~3) + n )
static const uint8_t segment_pin_interleaved[] =
/*    A     B     C     D     E     F    G1    G2     H     J     K     L     M     N    Dp    nc -> outX */
 { I(12),I(13), I(1), I(6), I(0),I(15),I(11), I(7),I(14),I(10), I(9), I(4), I(3), I(2), I(5), I(8) };
#undef I

/*
 *         ._  ___________  _.
 *         | \ \____A____/ / |
 *         | |._    _    _.| |
 *         | || \  | |  / || |
 *         |F| \H\ |J| /K/ |B|
 *         | |  \_\|_|/_/  | |
 *         |_| ____   ____ |_|
 *          _ <_G1_> <_G2_> _
 *         | |   ._._._.   | |
 *         | |  / /| |\ \  | |
 *         |E| /N/ |M| \L\ |C|
 *         | ||_/  |_|  \_|| |
 *         | | ___________ | |   __
 *         |/ /_____D_____\ \|  (Dp)
 *
 *
 * Frame sent over serial:
 *
 *                  [  0  1 ] } 2x 16x little-endian uint16 in range: [0x0000..0xff00] (A B C D E F G1 G2 H J K L M N Dp nc)
 *                  [  2  3 ]   same...
 *                  [  4  5 ]   ...
 *                  [  6  7 ]
 *                  [  8  9 ]
 *                  [  A  B ]
 *                  [  C  D ]
 *                  [  E  F ]
 *                  [ 10 11 ]
 *                  [ 12 13 ]
 *                  [ 14 15 ]
 *                  [ 16 17 ]
 *                  [ 18 19 ]
 *                  [ 1A 1B ]
 *                  [ 1C 1D ]
 *                  [ 1E 1F ]
 *                            + END OF FRAME MARKER "\xff\xff\xff\xf0"
 *
 *                Frame internal mapping:
 * 
 *                 /[ R0 R1 ] \_N[0..15] segment bits re-ordered to match driver pins
 *                | [ R2 R3 ] /
 *                | [ R0 R1 ] \_N[16..31]
 *  north channel-| [ R2 R3 ] /
 *                | [ R0 R1 ] \_N[32..47]
 *                | [ R2 R3 ] /
 *                | [ R0 R1 ] \_N[48..63]
 *                 \[ R2 R3 ] /
 *                 /[ R0 R1 ] \_S[48..63]
 *                | [ R2 R3 ] /
 *                | [ R0 R1 ] \_S[32..47]
 *  south channel-| [ R2 R3 ] /
 *                | [ R0 R1 ] \_S[16..31]
 *                | [ R2 R3 ] /
 *                | [ R0 R1 ] \_S[0..15]
 *                 \[ R2 R3 ] /
 *
 * R0-R3: 4 rows, (selected using 2 I/O pins, similar to rows in a normal matrix display)
 *
 * 1 byte/segment, the 2 channels are interleaved every 4 bytes
 * FRAME: [ ROW_0 ROW_1 ROW_2 ROW_3 ]
 * ROW_X: [ N0 N1 N2 N3 S0 S1 S2 S3 N4 N5 N6 N7 S4 ... S59 N60 N61 N62 N63 S60 S61 S62 S63 ]
 */

static uint8_t buf15[N_BITS_PER_CHANNEL] __attribute__((aligned(4)));
static uint8_t buf14[N_BITS_PER_CHANNEL] __attribute__((aligned(4)));
static uint8_t buf13[N_BITS_PER_CHANNEL] __attribute__((aligned(4)));
static uint8_t buf12[N_BITS_PER_CHANNEL] __attribute__((aligned(4)));
static uint8_t bufx[N_BITS_PER_CHANNEL] __attribute__((aligned(4)));
static uint8_t bufy[N_BITS_PER_CHANNEL] __attribute__((aligned(4)));

typedef struct
{
	uint8_t high_bits[N_LEDS];
	uint8_t low_bits[N_LEDS];
} frame_t;

static frame_t frame_a __attribute__((aligned(4)));
static frame_t frame_b __attribute__((aligned(4)));

static uint8_t zeroes[N_BITS_PER_ROW] __attribute__((aligned(4)));

static frame_t * volatile cur_frame;
static frame_t * volatile next_frame;
static frame_t * volatile draw_frame;

static int cur_row;
static int cur_pos;
static uint16_t iter;
static int is_2nd_half = 0;

#define RECV_BUF_SZ (128)
static volatile uint8_t recv_buf[RECV_BUF_SZ];
/*
max_in=0xfd
max_val=0xff00
gamma=2.5

factor = max_val / (max_in**gamma)
gamma_map = [ int( (x**gamma * factor) + .5 ) for x in range(max_in+1) ]

print ("""
const uint16_t gamma_map[] =
{
    """+','.join(str(x) for x in gamma_map)+""",
};""")

*/

static const uint16_t gamma_map[] =
{
	0,0,0,1,2,4,6,8,12,16,20,26,32,39,47,56,66,76,88,101,115,130,146,163,181,200,221,243,266,290,316,343,371,401,432,465,499,534,571,609,649,690,733,777,823,871,920,971,1023,1078,1133,1191,1250,1311,1374,1438,1505,1573,1643,1714,1788,1863,1941,2020,2101,2184,2269,2356,2445,2536,2629,2723,2820,2919,3020,3123,3229,3336,3445,3557,3670,3786,3904,4024,4146,4271,4398,4527,4658,4791,4927,5065,5205,5348,5493,5640,5790,5942,6096,6253,6412,6573,6737,6904,7072,7244,7417,7593,7772,7953,8137,8323,8512,8703,8897,9093,9292,9494,9698,9905,10114,10326,10541,10758,10978,11201,11426,11654,11885,12119,12355,12594,12836,13080,13327,13577,13830,14086,14344,14605,14870,15137,15406,15679,15955,16233,16514,16799,17086,17376,17669,17965,18264,18566,18870,19178,19489,19803,20120,20440,20762,21088,21417,21749,22085,22423,22764,23108,23456,23807,24160,24517,24877,25240,25607,25976,26349,26725,27104,27486,27871,28260,28652,29047,29446,29848,30252,30661,31072,31487,31905,32327,32752,33180,33611,34046,34484,34926,35371,35819,36271,36726,37184,37646,38111,38580,39052,39528,40007,40490,40976,41465,41958,42455,42955,43459,43966,44476,44990,45508,46029,46554,47083,47615,48150,48689,49232,49779,50329,50882,51440,52001,52565,53134,53705,54281,54860,55443,56030,56620,57215,57812,58414,59019,59628,60241,60858,61478,62102,62730,63362,63998,64637,65280,
};


enum
{
	B15, B14, B13, B12, BX, BY,
	P15, P14, P13, P12, P11, P10, P9, P8,
	P7, P6, P5, P4, P3, P2, P1, P0,
	ZX, /* send zeroes */
//	OFF,
	E0, E1, E2, E3, E4, E5, E6, E7, E8,
	ZZZ,
	SWITCH,
};

#define TABLE_COLS (19)
#define TABLE_ROWS (16)
#define TABLE_SIZE (TABLE_COLS*TABLE_ROWS)

/* SysTick dispatch table for BCM bitbang & precomputation */
static const uint8_t dtable[TABLE_SIZE] =
{
/*	 15    .    .    .    .    .    .    .   14    .    .    .   13    .   12  11/10 dith */

	B15, ZZZ, P14, P13, P12, ZZZ, P11, ZZZ, B14, ZZZ,  P8, P15, B13, ZZZ, B12,  BX,  BY, E8, SWITCH,
	B15, ZZZ, P14, P13, P12, ZZZ, P10, ZZZ, B14, ZZZ,  P4, P15, B13, ZZZ, B12,  BX,  BY, E4, SWITCH,
	B15, ZZZ, P14, P13, P12, ZZZ, P11, ZZZ, B14, ZZZ,  P6, P15, B13, ZZZ, B12,  BX,  BY, E6, SWITCH,
	B15, ZZZ, P14, P13, P12, ZZZ,  P9, ZZZ, B14, ZZZ,  P2, P15, B13, ZZZ, B12,  BX,  BY, E2, SWITCH,

	B15, ZZZ, P14, P13, P12, ZZZ, P11, ZZZ, B14, ZZZ,  P7, P15, B13, ZZZ, B12,  BX,  BY, E7, SWITCH,
	B15, ZZZ, P14, P13, P12, ZZZ, P10, ZZZ, B14, ZZZ,  P3, P15, B13, ZZZ, B12,  BX,  BY, E3, SWITCH,
	B15, ZZZ, P14, P13, P12, ZZZ, P11, ZZZ, B14, ZZZ,  P5, P15, B13, ZZZ, B12,  BX,  BY, E5, SWITCH,
	B15, ZZZ, P14, P13, P12, ZZZ,  ZX, ZZZ, B14, ZZZ,  P1, P15, B13, ZZZ, B12,  BX,  BY, E2, SWITCH,


	B15, ZZZ, P14, P13, P12, ZZZ, P11, ZZZ, B14, ZZZ,  P8, P15, B13, ZZZ, B12,  BX,  BY, E8, SWITCH,
	B15, ZZZ, P14, P13, P12, ZZZ, P10, ZZZ, B14, ZZZ,  P4, P15, B13, ZZZ, B12,  BX,  BY, E4, SWITCH,
	B15, ZZZ, P14, P13, P12, ZZZ, P11, ZZZ, B14, ZZZ,  P6, P15, B13, ZZZ, B12,  BX,  BY, E6, SWITCH,
	B15, ZZZ, P14, P13, P12, ZZZ,  P9, ZZZ, B14, ZZZ,  P2, P15, B13, ZZZ, B12,  BX,  BY, E2, SWITCH,

	B15, ZZZ, P14, P13, P12, ZZZ, P11, ZZZ, B14, ZZZ,  P7, P15, B13, ZZZ, B12,  BX,  BY, E7, SWITCH,
	B15, ZZZ, P14, P13, P12, ZZZ, P10, ZZZ, B14, ZZZ,  P3, P15, B13, ZZZ, B12,  BX,  BY, E3, SWITCH,
	B15, ZZZ, P14, P13, P12, ZZZ, P11, ZZZ, B14, ZZZ,  P5, P15, B13, ZZZ, B12,  BX,  BY, E5, SWITCH,
	B15, ZZZ, P14, P13, P12, ZZZ,  ZX, ZZZ, B14, ZZZ,  P0, P15, B13, ZZZ, B12,  BX,  BY, E1, SWITCH,

};

const uint32_t select_row[] =
{
	CLEAR ( BIT_SELECT_A ) | CLEAR ( BIT_SELECT_B ),
	SET   ( BIT_SELECT_A ) |   SET ( BIT_SELECT_B ),
	CLEAR ( BIT_SELECT_A ) |   SET ( BIT_SELECT_B ),
	SET   ( BIT_SELECT_A ) | CLEAR ( BIT_SELECT_B ),
};

//static void off(void)              { GPIOA->BSRR = CLEAR(BIT_ENABLE_HIGH) | SET(BIT_NOT_OUTPUT_ENABLE); }

static void switch_addr(void) { GPIOA->BSRR = select_row[cur_row]; }

static void bitbang_15(void)       { bitbang64_clk_stm32(buf15, (void *)GPIOA);
                                     GPIOA->BSRR = select_row[cur_row];
	                                 GPIOA->BSRR = SET(BIT_ENABLE_HIGH); }
static void bitbang_14(void)       { bitbang64_clk_stm32(buf14, (void *)GPIOA); }
static void bitbang_13(void)       { bitbang64_clk_stm32(buf13, (void *)GPIOA); }
static void bitbang_12(void)       { bitbang64_clk_stm32(buf12, (void *)GPIOA); }
static void bitbang_x(void)        { bitbang64_clk_stm32(bufx,  (void *)GPIOA); }
static void bitbang_y_no_enable(void) { bitbang64_clk_no_enable_stm32(bufy,  (void *)GPIOA); }

static void prepare_15(void) { draw_frame = cur_frame;
                               cur_pos += N_BITS_PER_ROW; if (cur_pos>=N_LEDS) cur_pos = 0;
                               precomp64(buf15, &draw_frame->high_bits[cur_pos], 7, X4(BIT_NOT_OUTPUT_ENABLE));}
static void prepare_14(void) { precomp64(buf14, &draw_frame->high_bits[cur_pos], 6, X4(BIT_ENABLE_HIGH)); }
static void prepare_13(void) { precomp64(buf13, &draw_frame->high_bits[cur_pos], 5, X4(BIT_ENABLE_HIGH)); }
static void prepare_12(void) { precomp64(buf12, &draw_frame->high_bits[cur_pos], 4, X4(BIT_ENABLE_HIGH)); }
static void prepare_11(void) { precomp64(bufx,  &draw_frame->high_bits[cur_pos], 3, X4(BIT_ENABLE_HIGH)); }
static void prepare_10(void) { precomp64(bufx,  &draw_frame->high_bits[cur_pos], 2, X4(BIT_ENABLE_HIGH)); }
static void prepare_9(void)  { precomp64(bufx,  &draw_frame->high_bits[cur_pos], 1, X4(BIT_ENABLE_HIGH)); }
static void prepare_8(void)  { precomp64(bufy,  &draw_frame->high_bits[cur_pos], 0, X4(BIT_ENABLE_HIGH)); }
static void prepare_7(void)  { precomp64(bufy,  &draw_frame->low_bits[cur_pos], 7, X4(BIT_ENABLE_HIGH)); }
static void prepare_6(void)  { precomp64(bufy,  &draw_frame->low_bits[cur_pos], 6, X4(BIT_ENABLE_HIGH)); }
static void prepare_5(void)  { precomp64(bufy,  &draw_frame->low_bits[cur_pos], 5, X4(BIT_ENABLE_HIGH)); }
static void prepare_4(void)  { precomp64(bufy,  &draw_frame->low_bits[cur_pos], 4, X4(BIT_ENABLE_HIGH)); }
static void prepare_3(void)  { precomp64(bufy,  &draw_frame->low_bits[cur_pos], 3, X4(BIT_ENABLE_HIGH)); }
static void prepare_2(void)  { precomp64(bufy,  &draw_frame->low_bits[cur_pos], 2, X4(BIT_ENABLE_HIGH)); }
static void prepare_1(void)  { precomp64(bufy,  &draw_frame->low_bits[cur_pos], 1, X4(BIT_ENABLE_HIGH)); }
static void prepare_0(void)  { precomp64(bufy,  &draw_frame->low_bits[cur_pos], 0, X4(BIT_ENABLE_HIGH)); }

//#define FLIP_OFF (SET(BIT_NOT_OUTPUT_ENABLE)|CLEAR(BIT_ENABLE_HIGH))
#define FLIP_OFF (SET(BIT_NOT_OUTPUT_ENABLE))
#define FLIP_ON  (SET(BIT_ENABLE_HIGH)|CLEAR(BIT_NOT_OUTPUT_ENABLE))
#define SYSTICK_PERIOD ((uint32_t)(F_SYS_TICK_CLK/(TABLE_SIZE*100)/4 ))
#define SYSTICK_CYCLES ((uint32_t)(8*SYSTICK_PERIOD))

static void enable_8(void) { write_wait_write(&GPIOA->BSRR, FLIP_ON, FLIP_OFF, SYSTICK_CYCLES>>1); cur_row = (cur_row+1)&(N_ROWS-1); if (cur_row) iter -= TABLE_COLS; }
static void enable_7(void) { write_wait_write(&GPIOA->BSRR, FLIP_ON, FLIP_OFF, SYSTICK_CYCLES>>2); cur_row = (cur_row+1)&(N_ROWS-1); if (cur_row) iter -= TABLE_COLS; }
static void enable_6(void) { write_wait_write(&GPIOA->BSRR, FLIP_ON, FLIP_OFF, SYSTICK_CYCLES>>3); cur_row = (cur_row+1)&(N_ROWS-1); if (cur_row) iter -= TABLE_COLS; }
static void enable_5(void) { write_wait_write(&GPIOA->BSRR, FLIP_ON, FLIP_OFF, SYSTICK_CYCLES>>4); cur_row = (cur_row+1)&(N_ROWS-1); if (cur_row) iter -= TABLE_COLS; }
static void enable_4(void) { write_wait_write(&GPIOA->BSRR, FLIP_ON, FLIP_OFF, SYSTICK_CYCLES>>5); cur_row = (cur_row+1)&(N_ROWS-1); if (cur_row) iter -= TABLE_COLS; }
static void enable_3(void) { write_wait_write(&GPIOA->BSRR, FLIP_ON, FLIP_OFF, SYSTICK_CYCLES>>6); cur_row = (cur_row+1)&(N_ROWS-1); if (cur_row) iter -= TABLE_COLS; }
static void enable_2(void) { write_wait_write(&GPIOA->BSRR, FLIP_ON, FLIP_OFF, SYSTICK_CYCLES>>7); cur_row = (cur_row+1)&(N_ROWS-1); if (cur_row) iter -= TABLE_COLS; }
static void enable_1(void) { write_wait_write(&GPIOA->BSRR, FLIP_ON, FLIP_OFF, SYSTICK_CYCLES>>8); cur_row = (cur_row+1)&(N_ROWS-1); if (cur_row) iter -= TABLE_COLS; }
static void enable_0(void) { write_wait_write(&GPIOA->BSRR, FLIP_ON, FLIP_OFF, SYSTICK_CYCLES>>9); cur_row = (cur_row+1)&(N_ROWS-1); if (cur_row) iter -= TABLE_COLS; }

static void zero_x(void) { precomp64(bufx, zeroes, 0, X4(BIT_ENABLE_HIGH)); }

static void ret(void) { }

typedef void (*func_t)(void);

const func_t dispatch[] =
{
	[B15] = bitbang_15,
	[B14] = bitbang_14,
	[B13] = bitbang_13,
	[B12] = bitbang_12,
	[BX] = bitbang_x,
	[BY] = bitbang_y_no_enable,
	[P15] = prepare_15,
	[P14] = prepare_14,
	[P13] = prepare_13,
	[P12] = prepare_12,
	[P11] = prepare_11,
	[P10] = prepare_10,
	[P9] = prepare_9,
	[P8] = prepare_8,
	[P7] = prepare_7,
	[P6] = prepare_6,
	[P5] = prepare_5,
	[P4] = prepare_4,
	[P3] = prepare_3,
	[P2] = prepare_2,
	[P1] = prepare_1,
	[P0] = prepare_0,

	[E8] = enable_8,
	[E7] = enable_7,
	[E6] = enable_6,
	[E5] = enable_5,
	[E4] = enable_4,
	[E3] = enable_3,
	[E2] = enable_2,
	[E1] = enable_1,
	[E0] = enable_0,

	[ZX] = zero_x,
//	[OFF] = off,
	[ZZZ]= ret,
	[SWITCH]= switch_addr,
};

void SysTick_Handler(void)
{
	dispatch[dtable[iter]]();

	if (iter < TABLE_SIZE-1)
		iter = iter+1;
	else
		iter = 0;
}

static void init(void)
{
	RCC->AHBENR |= RCC_AHBENR_GPIOAEN | RCC_AHBENR_GPIOBEN; /* enable clock on GPIO A & B */
	GPIOA->ODR = BIT_NOT_OUTPUT_ENABLE;
	GPIOA->MODER = SWD|O(0)|O(1)|O(2)|O(4)|O(5)|O(6)|O(7)|O(9)|O(10);

	GPIOA->OSPEEDR = OSPEED_SWD                         |
	                 OSPEED_HIGH(PIN_LATCH)             |
	                 OSPEED_HIGH(PIN_DATA_SOUTH)        |
	                 OSPEED_HIGH(PIN_DATA_NORTH)        |
	                 OSPEED_HIGH(PIN_CLK_SOUTH)         |
	                 OSPEED_HIGH(PIN_CLK_NORTH)         |
	                 OSPEED_HIGH(PIN_ENABLE_HIGH)       |
	                 OSPEED_HIGH(PIN_NOT_OUTPUT_ENABLE) ;

	GPIOB->ODR = 0*BIT_ENABLE_LOW;
	GPIOB->MODER = O(1);

	/* There aren't enough lines from the teensy to drive 30 boards in
	 * parallel, so the 16 uarts each send two frames. swdio pulled to ground
	 * on the backplane tells the board it should display the first frame.
	 * (A floating swdio is internally pulled up by default)
	 *
	 * NOTE: this makes this code work differently with a debugger attached on startup
	 *
	 * - attached: swdio pulled to ground on startup, display first frames
	 * - detached: swdio pulled up internally on startup, display second frames
	 *
	 */
	is_2nd_half = !!( GPIOA->IDR & 1<<13 );

	clock48mhz();
	usart1_rx_pa3_dma3_enable(recv_buf, RECV_BUF_SZ, 48e6/1e6);

	cur_frame = &frame_a;
	next_frame = &frame_b;
	cur_row = 0;
	iter = 0;

	int i;
	for (i=0; i<N_LEDS; i++)
	{
		frame_a. low_bits[i] =
		frame_b. low_bits[i] = 0;
		frame_a.high_bits[i] =
		frame_b.high_bits[i] = 0;
	}

	for (i=0; i<N_BITS_PER_ROW; i++)
		zeroes[i] = 0;

	cur_pos = -N_BITS_PER_ROW; /* pre-compensate for the first invocation of prepare_10() */
	prepare_15();

	enable_sys_tick(SYSTICK_PERIOD);
}

/* protocol */

#define END_OF_FRAME (0xfe)
#define DISCARD_FRAME (0xff)

static int dma_getchar(void)
{
	static uint32_t last = 0;
	if (last == 0)
		last = RECV_BUF_SZ;
	while (last == DMA1_Channel3->CNDTR);
	last--;
	return recv_buf[RECV_BUF_SZ-1-last];
}

static int read_next_frame(void)
{
	int i, c, v, digit_location, chip_delta, seg;

	if (is_2nd_half)
		for (i=0; i<N_LEDS; i++)
			if(dma_getchar() >= END_OF_FRAME)
				return 0;

	/* do the mapping to an easy-to-use internal representation once */
#define NEXT_CHIP (N_PINS_PER_CHIP*N_CHANNELS)
#define NEXT_ROW (N_BITS_PER_ROW)
#define SEGMENT_MASK (N_PINS_PER_CHIP-1)
#define CHIP_MASK (N_PINS_PER_CHIP*N_ROWS-1)

	chip_delta = NEXT_CHIP - N_ROWS*NEXT_ROW; /* pre-undo first iteration */
	digit_location = - chip_delta - NEXT_ROW;
	for (i=0; i<N_LEDS; i++)
	{
		seg = SEGMENT_MASK & i;
		if (seg == 0)
		{
			digit_location += NEXT_ROW;
			if ( (i & CHIP_MASK) == 0 )
			{
				digit_location += chip_delta;
				if (i == N_LEDS/N_CHANNELS)
				{
					digit_location = (N_CHIPS_PER_CHANNEL-1)*NEXT_CHIP+CHANNEL_OFFSET;
					chip_delta = - NEXT_CHIP - N_ROWS*NEXT_ROW;
				}
			}
		}
		c = dma_getchar();
		if (c>=END_OF_FRAME)
			break;

		v = gamma_map[c];
		next_frame->high_bits[digit_location+segment_pin_interleaved[seg]] = v>>8;
		next_frame->low_bits [digit_location+segment_pin_interleaved[seg]] = v;
	}

	while (c<END_OF_FRAME)
		c = dma_getchar();

	return c != DISCARD_FRAME;
}

int main(void)
{
	init();

	for(;;)
	{
		while (! read_next_frame() );
		frame_t *tmp = cur_frame;
		cur_frame = next_frame;
		next_frame = tmp;
		while (draw_frame == next_frame);
	}

	return 0;
}

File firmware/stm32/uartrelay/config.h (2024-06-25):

#ifndef CONFIG_H
#define CONFIG_H

#include "util.h"

/* configurable parameters (SRAM needed: XXX) */

#define T_PULSE (47)

#ifndef N_VALUES_PER_LED
#define N_VALUES_PER_LED  (3)
#endif

#ifndef N_LEDS_PER_STRIP
#define N_LEDS_PER_STRIP (44)
#endif

#define DMA_WIDTH (8)

#define OUT_PIN (0)

#define BAUDRATE (1500000)

#endif // CONFIG_H

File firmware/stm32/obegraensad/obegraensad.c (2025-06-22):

/* Joining the FPGA cult next project, I promise */

#include <stdlib.h>
#include <string.h>

#include "obegraensad.h"
#include "util.h"

typedef struct __attribute__((packed,aligned(4)))
{
	uint8_t bit[16][N_BITS_PER_CHANNEL]; 
} frame_t;

frame_t frame_a, frame_b;

static frame_t * volatile cur_frame;
static frame_t * volatile next_frame;
static frame_t * volatile draw_frame;

static uint16_t iter;

enum
{
	B15, B14, B13, B12, B11, B10, B9, B8,
	B7, B6, B5, B4, B3, B2, B1, B0,
	E0, E1, E2, E3, E4, E5, E6, E7, E8,
	ZZZ,
};

/* SysTick dispatch table for BCM bitbang */
static const uint8_t dtable[] =
{
/*	 15    .    .    .    .    .    .    .   14    .    .    .   13    .   12  11/10 dith */

	B15, ZZZ, ZZZ, ZZZ, ZZZ, ZZZ, ZZZ, ZZZ, B14, ZZZ, ZZZ, ZZZ, B13, ZZZ, B12, B11,  B8, E8,
	B15, ZZZ, ZZZ, ZZZ, ZZZ, ZZZ, ZZZ, ZZZ, B14, ZZZ, ZZZ, ZZZ, B13, ZZZ, B12, B10,  B4, E4,
	B15, ZZZ, ZZZ, ZZZ, ZZZ, ZZZ, ZZZ, ZZZ, B14, ZZZ, ZZZ, ZZZ, B13, ZZZ, B12, B11,  B6, E6,
	B15, ZZZ, ZZZ, ZZZ, ZZZ, ZZZ, ZZZ, ZZZ, B14, ZZZ, ZZZ, ZZZ, B13, ZZZ, B12,  B9,  B2, E2,

	B15, ZZZ, ZZZ, ZZZ, ZZZ, ZZZ, ZZZ, ZZZ, B14, ZZZ, ZZZ, ZZZ, B13, ZZZ, B12, B11,  B7, E7,
	B15, ZZZ, ZZZ, ZZZ, ZZZ, ZZZ, ZZZ, ZZZ, B14, ZZZ, ZZZ, ZZZ, B13, ZZZ, B12, B10,  B3, E3,
	B15, ZZZ, ZZZ, ZZZ, ZZZ, ZZZ, ZZZ, ZZZ, B14, ZZZ, ZZZ, ZZZ, B13, ZZZ, B12, B11,  B5, E5,
	B15, ZZZ, ZZZ, ZZZ, ZZZ, ZZZ, ZZZ, ZZZ, B14, ZZZ, ZZZ, ZZZ, B13, ZZZ, B12,       B1, E2,

	B15, ZZZ, ZZZ, ZZZ, ZZZ, ZZZ, ZZZ, ZZZ, B14, ZZZ, ZZZ, ZZZ, B13, ZZZ, B12, B11,  B8, E8,
	B15, ZZZ, ZZZ, ZZZ, ZZZ, ZZZ, ZZZ, ZZZ, B14, ZZZ, ZZZ, ZZZ, B13, ZZZ, B12, B10,  B4, E4,
	B15, ZZZ, ZZZ, ZZZ, ZZZ, ZZZ, ZZZ, ZZZ, B14, ZZZ, ZZZ, ZZZ, B13, ZZZ, B12, B11,  B6, E6,
	B15, ZZZ, ZZZ, ZZZ, ZZZ, ZZZ, ZZZ, ZZZ, B14, ZZZ, ZZZ, ZZZ, B13, ZZZ, B12,  B9,  B2, E2,

	B15, ZZZ, ZZZ, ZZZ, ZZZ, ZZZ, ZZZ, ZZZ, B14, ZZZ, ZZZ, ZZZ, B13, ZZZ, B12, B11,  B7, E7,
	B15, ZZZ, ZZZ, ZZZ, ZZZ, ZZZ, ZZZ, ZZZ, B14, ZZZ, ZZZ, ZZZ, B13, ZZZ, B12, B10,  B3, E3,
	B15, ZZZ, ZZZ, ZZZ, ZZZ, ZZZ, ZZZ, ZZZ, B14, ZZZ, ZZZ, ZZZ, B13, ZZZ, B12, B11,  B5, E5,
	B15, ZZZ, ZZZ, ZZZ, ZZZ, ZZZ, ZZZ, ZZZ, B14, ZZZ, ZZZ, ZZZ, B13, ZZZ, B12,       B0, E1,

};

#define TABLE_SIZE (sizeof(dtable)/sizeof(dtable[0]))

static void bitbang_15(void)       { bitbang64_clk_stm32(cur_frame->bit[15], (void *)GPIO_OUT); draw_frame = cur_frame; }
static void bitbang_14(void)       { bitbang64_clk_stm32(draw_frame->bit[14], (void *)GPIO_OUT); }
static void bitbang_13(void)       { bitbang64_clk_stm32(draw_frame->bit[13], (void *)GPIO_OUT); }
static void bitbang_12(void)       { bitbang64_clk_stm32(draw_frame->bit[12], (void *)GPIO_OUT); }
static void bitbang_11(void)       { bitbang64_clk_stm32(draw_frame->bit[11], (void *)GPIO_OUT); }
static void bitbang_10(void)       { bitbang64_clk_stm32(draw_frame->bit[10], (void *)GPIO_OUT); }
static void bitbang_9(void)        { bitbang64_clk_stm32(draw_frame->bit[ 9], (void *)GPIO_OUT); }
static void bitbang_8(void) { bitbang64_clk_no_enable_stm32(draw_frame->bit[8],  (void *)GPIO_OUT); }
static void bitbang_7(void) { bitbang64_clk_no_enable_stm32(draw_frame->bit[7],  (void *)GPIO_OUT); }
static void bitbang_6(void) { bitbang64_clk_no_enable_stm32(draw_frame->bit[6],  (void *)GPIO_OUT); }
static void bitbang_5(void) { bitbang64_clk_no_enable_stm32(draw_frame->bit[5],  (void *)GPIO_OUT); }
static void bitbang_4(void) { bitbang64_clk_no_enable_stm32(draw_frame->bit[4],  (void *)GPIO_OUT); }
static void bitbang_3(void) { bitbang64_clk_no_enable_stm32(draw_frame->bit[3],  (void *)GPIO_OUT); }
static void bitbang_2(void) { bitbang64_clk_no_enable_stm32(draw_frame->bit[2],  (void *)GPIO_OUT); }
static void bitbang_1(void) { bitbang64_clk_no_enable_stm32(draw_frame->bit[1],  (void *)GPIO_OUT); }
static void bitbang_0(void) { bitbang64_clk_no_enable_stm32(draw_frame->bit[0],  (void *)GPIO_OUT); }

//#define FLIP_OFF (SET(BIT_NOT_OUTPUT_ENABLE)|CLEAR(BIT_ENABLE_HIGH))
#define FLIP_OFF (SET(BIT_NOT_OUTPUT_ENABLE))
#define FLIP_ON  (CLEAR(BIT_NOT_OUTPUT_ENABLE))
#define SYSTICK_PERIOD ((uint32_t)(F_SYS_TICK_CLK/(TABLE_SIZE*200) ))
#define SYSTICK_CYCLES ((uint32_t)(8*SYSTICK_PERIOD))

static void enable_8(void) { write_wait_write(&GPIO_OUT_BSRR, FLIP_ON, FLIP_OFF, SYSTICK_CYCLES>>1); }
static void enable_7(void) { write_wait_write(&GPIO_OUT_BSRR, FLIP_ON, FLIP_OFF, SYSTICK_CYCLES>>2); }
static void enable_6(void) { write_wait_write(&GPIO_OUT_BSRR, FLIP_ON, FLIP_OFF, SYSTICK_CYCLES>>3); }
static void enable_5(void) { write_wait_write(&GPIO_OUT_BSRR, FLIP_ON, FLIP_OFF, SYSTICK_CYCLES>>4); }
static void enable_4(void) { write_wait_write(&GPIO_OUT_BSRR, FLIP_ON, FLIP_OFF, SYSTICK_CYCLES>>5); }
static void enable_3(void) { write_wait_write(&GPIO_OUT_BSRR, FLIP_ON, FLIP_OFF, SYSTICK_CYCLES>>6); }
static void enable_2(void) { write_wait_write(&GPIO_OUT_BSRR, FLIP_ON, FLIP_OFF, SYSTICK_CYCLES>>7); }
static void enable_1(void) { write_wait_write(&GPIO_OUT_BSRR, FLIP_ON, FLIP_OFF, SYSTICK_CYCLES>>8); }
static void enable_0(void) { write_wait_write(&GPIO_OUT_BSRR, FLIP_ON, FLIP_OFF, SYSTICK_CYCLES>>9); }

static void ret(void) { }

typedef void (*func_t)(void);

const func_t dispatch[] =
{

	[B15] = bitbang_15,
	[B14] = bitbang_14,
	[B13] = bitbang_13,
	[B12] = bitbang_12,
	[B11] = bitbang_11,
	[B10] = bitbang_10,
	[B9] = bitbang_9,
	[B8] = bitbang_8,
	[B7] = bitbang_7,
	[B6] = bitbang_6,
	[B5] = bitbang_5,
	[B4] = bitbang_4,
	[B3] = bitbang_3,
	[B2] = bitbang_2,
	[B1] = bitbang_1,
	[B0] = bitbang_0,

	[E8] = enable_8,
	[E7] = enable_7,
	[E6] = enable_6,
	[E5] = enable_5,
	[E4] = enable_4,
	[E3] = enable_3,
	[E2] = enable_2,
	[E1] = enable_1,
	[E0] = enable_0,

//	[OFF] = off,
	[ZZZ]= ret,
};

void SysTick_Handler(void)
{
	dispatch[dtable[iter]]();

	if (iter < TABLE_SIZE-1)
		iter = iter+1;
	else
		iter = 0;
}

static void init(void)
{
	init_io();

	cur_frame = &frame_a;
	next_frame = &frame_b;
	iter = 0;

	memset(&frame_a, BIT_NOT_OUTPUT_ENABLE, sizeof(frame_a));
	memset(&frame_b, BIT_NOT_OUTPUT_ENABLE, sizeof(frame_b));

	enable_sys_tick(SYSTICK_PERIOD);
}

#define GOOD          0
#define GOOD_00       1
#define GOOD_01_FE    2
#define GOOD_FF       3
#define GOOD_FFFF     4
#define GOOD_FFFFFF   5
#define BAD           6
#define BAD_FF        7
#define BAD_FFFF      8
#define BAD_FFFFFF    9

#define STATE_COUNT  10

#define GOOD_RETURN  11
#define BAD_RETURN   12

#define IN_00     0
#define IN_01_EF  1
#define IN_F0     2
#define IN_F1_FE  3
#define IN_FF     4
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

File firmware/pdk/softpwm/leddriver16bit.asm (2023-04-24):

.module softpwmpdk

BUFSIZE=8

.include "pdk.asm"
.include "delay.asm"
.include "settings.asm"
.include "uart2.asm"
.include "softpwm16.asm"

.area DATA (ABS)
.org 0x00


; bitwise ops need to have an address < 16

shiftreg:       .ds 1
error:          .ds 1

uart_state:     .ds 1
pin_mask_cur:   .ds 1

pinmask:        .ds 1
uart_tmp:       .ds 1

low1_staging:   .ds 1
low2_staging:   .ds 1
low3_staging:   .ds 1

refresh:        .ds 1

; word aligned
;...
p_lo:           .ds 1
p_hi:           .ds 1

out0:           .ds 1
out1:           .ds 1
cycle:          .ds 1
switch_channel: .ds 1

high:           .ds 1

high1:          .ds 1
high2:          .ds 1
high3:          .ds 1

high1_staging:  .ds 1
high2_staging:  .ds 1
high3_staging:  .ds 1

low:            .ds 1

low1:           .ds 1
low2:           .ds 1
low3:           .ds 1

dith:           .ds 1

dith1:          .ds 1
dith2:          .ds 1
dith3:          .ds 1

dith1_staging:  .ds 1
dith2_staging:  .ds 1
dith3_staging:  .ds 1

cmp1:           .ds 1
cmp2:           .ds 1
cmp3:           .ds 1

rem1:           .ds 1
rem2:           .ds 1
rem3:           .ds 1

low_highnib:    .ds 1
low_cur:        .ds 1
;
index:          .ds 1
cur_channel:    .ds 1

wait_count:     .ds 1
bit_count:      .ds 1
reset_count:    .ds 1

index_const:    .ds 1

.area CODE (ABS)
.org 0x00

.ifeq DEVICE-PMS150C
set_fuse FUSE_SET_LVR_2V75
.endif
; pull mosfets low first

clock_8mhz
brownout_erratum_workaround_init

;
;   ________                                                                        ________
;           ________0000000011111111222222223333333344444444555555556666666677777777
;                                                                                      /\
;           |-----------| (start_wait+1/2)*interval                                   9 1/2 baud
;        time to first sample (avg)                                               sample stop bit (avg)
;
;baud = 38400
;start_wait = 4
;bit_wait = 3
;check_interval = 64
;cycles = (.5+start_wait+8*bit_wait)*check_interval
;t = 9.5/baud
;freq = cycles/t
;print(freq)
FREQ=7372800

easypdk_calibrate FREQ, 3300

mov a, #PINMASK
mov pac, a
mov a, #0
mov pa, a

watchdog_enable
wdreset

find_settings settings p_lo
read_settings index_const

softpwm_init
uart_init

wdreset
softpwm

settings:
;.rept 256
;nop
;.endm
mov a, #INDEX
; update index by nopping (0x0000) out this instruction and appending a new mov, #NEW_INDEX
;

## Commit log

2020-08-03 esp32 + stm32 led ball driver
    [edgedriver-BOM-LCSC.csv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]
2020-08-07 add led info for another ball
2020-12-01 Version v2 (and v2.1 28 pad qfn)
    [edgedriver-BOM-LCSC.csv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]
2021-03-02 simplefy C bindings for cball module
    - simplefy C bindings for cball module
    - remappable leds
    - support float based framebuffer
    [uartpixel.py]
2021-03-02 add driver v3
    [edgedriver-BOM-LCSC.csv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]
2021-04-13 initial esp32 HTTP Server bindings
2021-04-17 esp_http_server bindings for micropython
    [config.py, esphttpd.py, main.py]
2021-04-28 fix stack UAF in case a request object escapes the handler
2021-04-28 screen attach directly
2021-04-30 fix session cookie retrieval
    [csrf.py]
2021-05-01 add socket info calls to request, use https only csrf cookies
2021-05-02 relay ball code
2021-05-02 relay ball binaries
2021-05-03 use LED remapping
2021-05-03 add LED groupings
2021-05-04 load circuits file
2021-05-06 source one file to config device for ampy wrappers
2021-05-12 Use a jitter hiding framebuffer queue
    [main.py, player.py, uartpixel.c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]
2021-05-13 rewrite frame sync routine to fix stalls
    [uartpixel.c]
2021-05-13 fix hang on exit
    [uartpixel.c]
2021-05-14 fix exception handling in player
    [player.py]
2021-11-16 add 16 bit uart frame pusher
2021-11-16 small changes to pcb
    [edgedriver.kicad_pcb]
2021-11-17 add aluball driver
    [edgedriver-BOM-LCSC.csv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]
2021-11-21 simplefy/decompose native framebuffer functions
2021-11-23 add 16 bit led driver rom
2021-12-29 add relay chip code
2022-02-21 add button press code for config mode
2022-02-22 fix access point race condition for failsafe mode
    [admin.py, main.py]
2022-03-11 relay tester
2022-03-25 clear leds between tests
2022-03-29 add relay pcb tester
    [edgedriver.kicad_pcb, edgedriver.sch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]
2022-03-29 add guide pcb
    [test_a.kicad_pcb, test_a.sch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]
2022-05-15 fix failsafe for when there is no configured network yet
    [main.py]
2022-07-17 add option to select open network in the failsafe menu
    [admin.py, config.py]
2022-07-19 show network info for last connection in failsafe mode
    [admin.py, config.py, main.py]
2022-08-14 update the configuration form correctly after altering wifi settings
    [admin.py, config.py]
2022-09-03 new driver versions
    [edgedriver-BOM-LCSC.csv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]
2022-11-29 use ThreadSafeFlag.clear()
2022-12-01 fix stack overflow in webserver thread while parsing json
    [main.py]
2022-12-01 fix race condition in uartpixel deinit
    [uartpixel.c]
2023-02-28 add relay binaries
2023-04-04 add uartball binary
2023-04-22 add watchdog to pdk code / improve frame reset
    [leddriver16bit.asm, softpwm16.asm, uart2.asm]
2023-04-23 add low-voltage-reset erratum workaround
    [leddriver16bit.asm, softpwm16.asm]
2023-04-24 sync led driver
2023-09-01 re-organize relayball code
2023-09-01 alternative driver pcb
    [edgedriver.kicad_pcb, edgedriver.sch]
2023-09-02 connect extra vdd/vss pins for high end chips 072 / 030CC
    [edgedriver.kicad_pcb, edgedriver.sch]
2023-10-04 add uart2 dma code to util.c
2023-10-04 add penta pcb
    [edgedriver.kicad_pcb, edgedriver.sch]
2023-10-16 add original led sphere coordinates
2023-10-16 add raw frame pushing for testing purposes
2023-11-01 add dma based ws2812 code
2023-12-02 new ws2812 driver implementation
2023-12-02 add support for led order configuration
2023-12-21 add pin number labels
    [edgedriver.kicad_pcb, edgedriver.sch]
2023-12-27 make multiwave use leds.groups['leds']
2024-01-07 add 16-pin output slim pcb
    [edgedriver.kicad_pcb, edgedriver.sch]
2024-01-07 don't drop into failsafe mode if there is no failsafe config
    [main.py]
2024-01-10 add wiring documentation & case svg
2024-01-18 add wiring diagrams
2024-01-18 fix topo button ordering
2024-01-18 fix wiring diagram
2024-02-04 ordered pcb
    [edgedriver.kicad_pcb]
2024-02-09 add monochrome support to uartpixel
2024-03-06 16 strip driver
    [edgedriver.kicad_pcb, edgedriver.sch]
2024-03-06 firmware for slim v2 driver
2024-05-18 fix dma base implementation
    [util.c]
2024-05-18 fix interrupt priority issue / test performance
2024-06-11 fix enabling output pin
2024-06-11 move dma based code to separate directory
2024-06-11 make dma transfer width configurable (untested)
2024-06-11 stm32: add gitignore
2024-06-11 [stm32] reorganise directory structure
    [stm32f0-openocd.cfg]
2024-06-11 rename dma implementation to ws2812_dma16
2024-06-14 [stm32] add uartrelay [untested]
2024-06-14 [stm32] [untested] add uartdemux, gpio_dma.[ch]
2024-06-19 test & fix bugs in uartdemux
    [gpio_dma.c, main.c]
2024-06-20 fix 8 bit width ws2812 DMA code
    [ws2812_dma.c]
2024-06-25 make uartrelay work
2024-06-25 restore correct initial output value
    [main.c]
2024-06-25 simple best effort corrupt frame discard
2024-07-02 invert bits of initial out frame
    [main.c]
2025-01-03 fix led position calculation
2025-01-04 add led computation code for chiral spheres to repo
2025-03-23 add relay firmware for new PCB version (pin PA0 used instead of pin PA4
2025-05-08 use stm32 as usbserial
    [edgedriver.kicad_pcb, edgedriver.kicad_sch]
2025-05-08 minor tweak
    [edgedriver.kicad_pcb]
2025-05-08 convert v3.2 to kicad 9
    [edgedriver.kicad_pcb, edgedriver.kicad_sch]
2025-05-27 auto-generate production files for v4
    [bomfile_jlc.csv, edgedriver.kicad_pcb, edgedriver.kicad_sch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]
2025-06-11 use correct LED map
    [obegraensad.c]
2025-06-12 fix glitch at startup
    [obegraensad.c]
2025-06-14 add disable boot pin sequece
2025-06-14 update sym lib table for old pcb
2025-06-14 add next/previous push button option
2025-06-16 use 74HCT245 as buffer
    [bomfile_jlc.csv, edgedriver.kicad_pcb, edgedriver.kicad_sch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]
2025-06-17 smooth out pwm waveforms a bit
2025-06-20 add driver wiring image
2025-06-20 add updated version of v4
    [bomfile_jlc.csv, edgedriver.kicad_pcb, edgedriver.kicad_sch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]
2025-06-22 split out io part from obegraensad driver to help porting
2025-06-24 add ESP32 software description
2025-07-02 slight tweak of VCC zone
    [edgedriver.kicad_pcb]
2025-07-04 fall back to failsafe mode if network configuration fails
    [admin.py, button.py, config.py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]
2025-07-04 play normal animations during failsafe mode
    [admin.py, main.py]
2025-07-05 didn't test the most common code-path Yesterday :,-)
    [main.py]
2025-07-05 fix crash when main network not configured
    [wifi.py]
2025-07-07 pretty-print network info
2025-07-07 configure internal pull-up to boot pin
2025-07-22 button bug
2025-07-23 add jump-to-configuration button to admin mode
2025-07-23 add 5v <-> vusb jumper (covered by solder mask)
    [edgedriver.kicad_pcb, edgedriver.kicad_sch]
2025-07-23 make fewer assumptions about thread scheduling when dropping to failsafe mode
    [main.py]
2025-09-06 actively drive unused pin to prevent noise
    just a precaution
    [main.c]
2025-09-14 add scripts using black magic probe
2025-09-14 add compact driver PCB
    [edgedriver.kicad_pcb, edgedriver.kicad_sch]
2025-09-14 remove old .pro project files
    [edgedriver.kicad_pcb, edgedriver.kicad_sch, test_a.kicad_pcb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]
2025-09-14 port pcbs to kicad 9
    [edgedriver.kicad_pcb, edgedriver.kicad_sch, edgedriver.sch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]
2025-09-14 get rid of rescued symbols
    [edgedriver.kicad_pcb, edgedriver.kicad_sch]
2025-09-14 add board outline svg
2025-09-14 add gerbers for minimal driver board
2025-09-14 add led definitions for the hexboard's horizontal bar
2025-09-14 import new sheets from pcbnew
    [edgedriver.kicad_pcb]
2025-09-14 Rename driver pcbs
    [bomfile_jlc.csv, edgedriver-BOM-LCSC.csv, edgedriver.kicad_pcb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]
2025-09-15 cleanup, restore driver_v1
    [edgedriver-BOM-LCSC.csv, pcb.kicad_pcb, pcb.kicad_sch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]
